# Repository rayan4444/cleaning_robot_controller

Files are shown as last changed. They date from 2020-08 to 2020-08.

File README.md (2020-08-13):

# Deck cleaning and staining robot

Hardware files for all the custom electronics in a deck cleaning and staining robot.
* Eagle files and documentation provided. See individual folder readme for details.
* Firmware for the STM32F407 was developed in C based on STM CubeMx libraries, but cannot be made public as of now.  

## Architecture

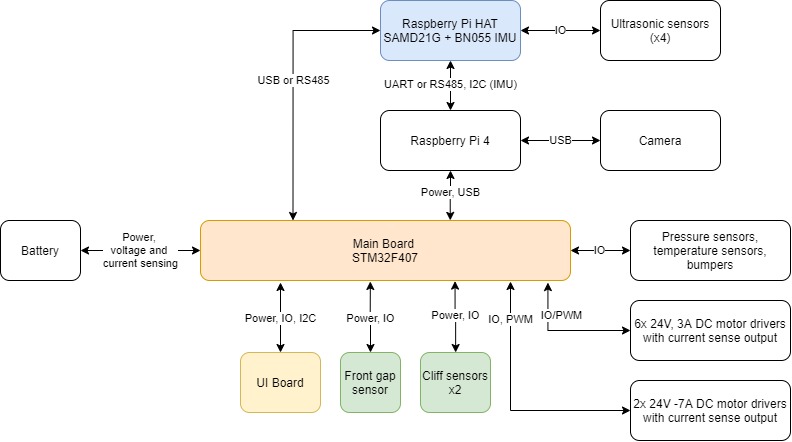
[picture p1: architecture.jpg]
Architecture


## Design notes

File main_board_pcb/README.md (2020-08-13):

# Robodeck Main Board

## Description
Main controller for motors, sensors and other peripherals. Features:
- 1x STM32F407 100pin microcontroller
- 6x 24V-3A motor drivers with fault detection, current sensing and current limiting
    - 2 with encoder lines
    - 4 simple
- 2x 24V- 10A motor drivers with fault detection, current sensing and current limiting
- 2x N-MOSFET Switches (up to 2A)
- 1x Hall effect current sensor on main input
- 1x Input voltage measurement
- 1x UART breakout
- 1x SPI breakout
- 1x I2C breakout
- 3x pressure sensor connectors
- 1x on board temperature and humidity sensor
- 2x connectors for external temperature sensors
- 2x Cliff sensor connectors
- 1x front gap sensor connector
- 2x 5V servo connectors
- 1x SMBUS BMS connector
- 1x RS-485 transceiver
- 2x bumpers connectors
- 1x SWD programming and debug header
- 1x UI board connector
- 2x USB outputs with power and data (up to 2.5A, data can be disconnected from one of the ports)
- 2x optional breakouts for Brushless ESC (share signal with high power motor drivers)
- 1x spare port breakout

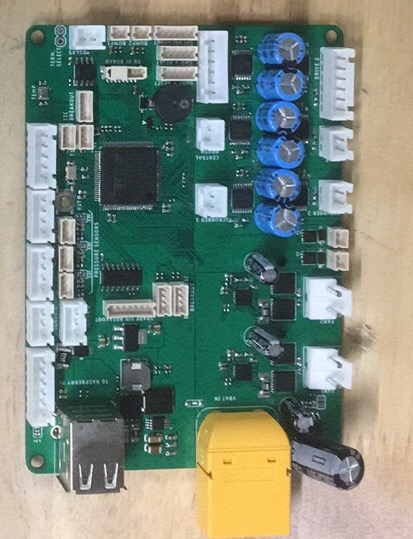
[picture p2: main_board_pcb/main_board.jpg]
main board

## Hardware connections
Microcontroller

|STM32 Pin | Peripheral| Signal|Notes|Test results|
|:---:|:---:|:---:|:---:|:---:|
|PC9 |**TIM3_CH4**|DRIVE1_A |PWM||
|PC12| GPIO OUT |DRIVE1_B||
|PD13| EXTI_13|DRIVE1_FAULT||  
|PB0| ADC1_CH8||DRIVE1_CURRENT||
|PB2| GPIO OUT| MOTOR_SLEEP |also BOOT1 pin|
|PC8|**TIM3_CH3**|DRIVE2_A |PWM|
|PC11|GPIO OUT|DRIVE2_B||
|PD12|EXTI_12|DRIVE2_FAULT||
|PB1| ADC_CH9|DRIVE2_CURRENT||
|PC6|**TIM3_CH1**|PRESSURE_PUMP_A|PWM|
|PA8|GPIO OUT|PRESSURE_PUMP_B||
|PD10|EXTI_10|PRESSURE_PUMP_FAULT||
|PC7|**TIM3_CH2**|CENTRAL_BRUSH_A|PWM|
|PC10|GPIO OUT|CENTRAL_BRUSH_B||
|PD11|EXTI_11|CENTRAL_BRUSH_FAULT||
|PC5|ADC1_CH5|CENTRAL_BRUSH_CURRENT||
|PE14|**TIM1_CH4**|SCRUBBER1_A|PWM|
|PE15|GPIO OUT|SCRUBBER1_B||
|PB15|EXTI_15|SCRUBBER1_FAULT||
|PA3|ADC1_CH3|SCRUBBER1_CURRENT|PWM|
|PE13|**TIM1_CH3**|SCRUBBER2_A|PWM|
|PE12|GPIO OUT|SCRUBBER2_B|| 
|PB14|EXTI_14|SCRUBBER2_FAULT||
|PC4|ADC1_CH14|SCRUBBER2_CURRENT||
|PD1|EXTI_1|BUMPER1||
|PD0|EXTI_0|BUMPER2||
|PD8|EXTI_8|ENCODER1||
|PD9|EXTI_9|ENCODER2|| 
|PD15|**TIM4_CH4**|SERVO1|PWM|
|PD14|**TIM4_CH3**|SERVO2|PWM|
|PB8|GPIO OUT|SOLENOID1||
|PB9|GPIO OUT|SOLENOID2||
|PE9|**TIM1_CH1**|STAINING_FAN1_A||
|PE8|GPIO OUT|STAINING_FAN1_B||
|PE6|EXTI_6|STAINING_FAN1_FAULT||
|PE11|**TIM1_CH2**|STAINING_FAN2_A||
|PE10|GPIO OUT|STAINING_FAN2_B||
|PE7|EXTI_7|STAINING_FAN2_FAULT||
|PB6|I2C1_SCL|SCL||
|PB7|i2C1_SDA|SDA||
|PD6|USART2_RX|RS485_RX||
|PD5|USART2_TX|RS485_TX||
|PE0|GPIO OUT|RS485_DIR||
|PB4|SPI1_MISO|MISO||
|PB5|SPI1_MOSI|MOSI||
|PD7|GPIO OUT|CS||
|PB3|SPI1_SCK|SCK||
|PA12|USB_DP|D_P||
|PA11|USB_DN|D_N||
|PA13|SWDIO|SWDIO||
|PA14|SWCLK|SWCLK||
|PA9|USART1_TX|USART1_TX|| 
|PA10|USART1_RX|USART1_RX||
|PB11|I2C2_SDA|SMBUS_SDA||
|PB10|I2C2_SCL|SMBUS_SCL|| 
|PB12|I2C2_SMBA|SMBUS_ALERT||
|PAB13|GPIO OUT|SMBUS_IO||
|PC2|ADC1_CH12|CLIFF1_OUT||
|PC3|ADC1_CH13|CLIFF2_OUT||
|PC0|ADC1_CH10|GAP_SENSE_1||
|PC1|ADC1_CH11|GAP_SENSE_2||
|PD4|EXTI_4|ONxOFF|from UI Board|
|PD3|EXTI_3|STARTxSTOP|from UI Board|
|PD2|EXTI_2|CLEANxSTAIN|from UI Board|
|PA4|DAC_1|GAP_CTL|to front gap sensor|
|PA5|DAC_2|CLIFF_CTL|to both cliff sensors|
|PC15|GPIO IN|EXT_TEMP2| DS18B20 temp sensor|  
|PC14|GPIO IN|EXT_TEMP1| DS18B20 temp sensor|  
|PA0|ADC1_CH0|PRESSURE1||
|PA6|ADC1_CH6|PRESSURE2||
|PA15|**TIM2_CH1**|BUZZER|st equivalent for tone library?|
|PA7|ADC1_CH7|PRESSURE3||GPIO OK|
|PE3|GPIO OUT|AMUX_S0|channel selection on analog mux|
|PE4|GPIO OUT|AMUX_S1|channel selection on analog mux|
|PE5|GPIO OUT|AMUX_S2|channel selection on analog mux|
|PA1|ADC1_CH1|AMUX_OUT|analog mux output|
|PA2|ADC1_CH2|LxCURRENT|current sensor output|
|PE1|GPIO OUT|SPARE_GPIO1||
|PE2|GPIO OUT|SPARE_GPIO2||

Signals from Analog Mux:

|Channel|S0/S1/S2|Signal|
|:---:|:---:|:---:|
|Y0|0/0/0|STAINING_FAN2_CURRENT|
|Y1|1/0/0|STAINING_FAN1_CURRENT|
|Y2|0/1/0|PRESSURE_PUMP_CURRENT|
|Y3|1/1/0|BAT_MEAS|
|Y4|1/0/0|-|
|Y5|1/0/1|SPARE_ANALOG1|
|Y6|1/1/0|-|
|Y7|1/1/1|SPARE_ANALOG2|

## Programming

- Using SWD: You can use a programmer (ex: Jlink or STlink) to program the baord via SWD. I included a cable with dupont wires to make it easier for you. If you have an ST development board (discovery or nucleo), you can usually re-use the STlink that is embedded on that baord to flash an external chip.

>if you are using Visual Studio Code, check out this [tutorial](https://github.com/rayan4444/vs_code_setup_tutorials/tree/master/STM32) to set up your development environment for STM32:
- Using UART: All STM32 chips come with a bootloader that lets you use UART to program them. If for some reason you don't want to use SWD to program the chip, you can still use UART. However this will require you to modify the PCB a little. In this version pin Boot 0 pulled low and pin PB2 pulled high. To use UART flashing Boot0 needs to be high and PB2 low. If needed, consult [this tutorial](http://stm32f4-discovery.net/2014/09/program-stm32f4-with-uart/)

## Errata
Manufacturing errors:
- test points names not marked on bottom silkscreen (layer missing from gerber?)
- inner layers shorted on milled slot for xt90 connector resulting in short between power and ground: to fix, saw off the milled slot on current boards. And in the future make sure to modify the library part

Errors noted when assembling:
- Pin 1 marking for analog mux is missing
- VBAT in polarity not marked on silkscreen
- XT90 connector polarity flipped (+ side on the circuit corresponds to the - side of the connector)
- Diode marking missing on FET switches
- +/-  markings missing on FET connectors
- wrong footprint for input 100uF through hole capacitor (too small)

Testing log:
- Board 0 (in shenzhen): many soldering issues. to be debugged gradually
- Board 1: 24V buck OK (5.35V, perfect), LDO OK (3.3V), Can prorgam through SWD. other peripherals not tested.
- Board 2: 24V buck OK (5.35V, perfect), LDO OK (3.3V), Can prorgam through SWD. other peripherals not tested.
- Board 3: 24V buck OK (5.38V, good), LDO OK (3.3V), Can program through SWD, other peripherals not tested.

> Some boards have burnt connectors. from debugging, sorry. one of them also has the main ninput capacitors missing, you can easily solder them up

>Note from Rayan: on all the boards I sent I did not solder the ferrite bead that connects GND and AGND because it made it easy to do basic tests. You can choose to use the ferrite bead from the BOM or short the connection with a 0 ohm resistor or some tin.

Other design errors:
- DRV8701 AVDD connected to 3.3v in V1. Make sure to disconnect AVDD from the 3.3v rail else the drivers overheat and don't work.
- Missing power on led indicator

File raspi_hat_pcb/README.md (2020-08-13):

# Raspberry Pi Hat

## Description
This board plugs onto a Raspberry pi and features:
- 1x ATSAMD21G18 MCU (Arduino Zero)
- 1x BNO055 IMU with jumpers to select the I2C host: Raspberry Pi or MCU
- 1x RS-485 transciever with jumper to select the UART host: Raspberry Pi or MCU
- 4x connectors for Ultrasonic sensors
- 1x FET driver for a small 5V fan to cool down the RPi

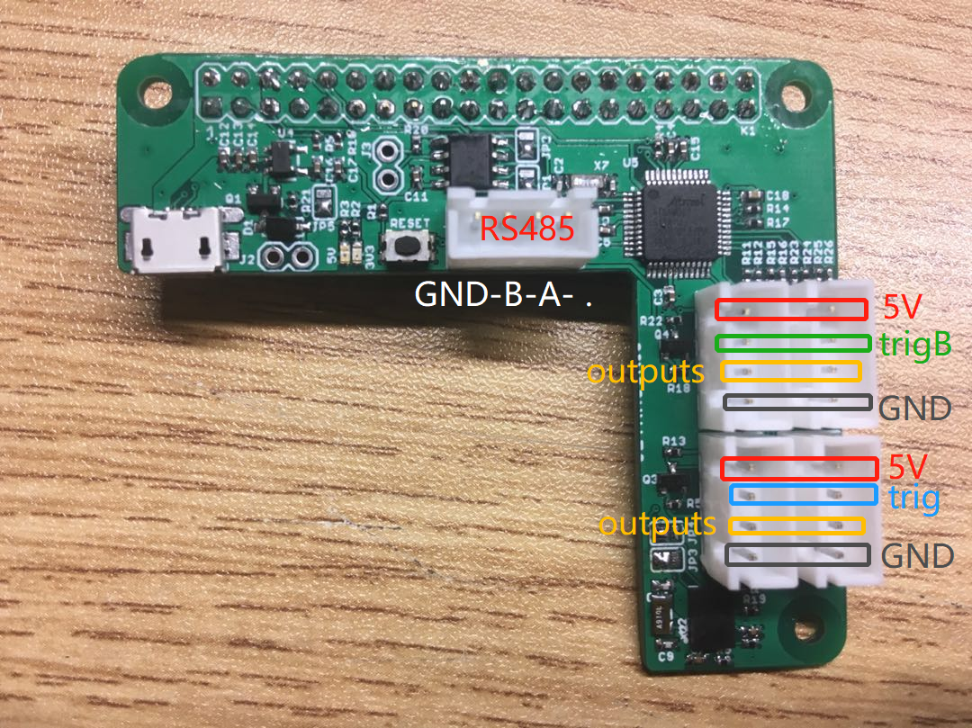
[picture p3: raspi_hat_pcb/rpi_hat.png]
Rpi hat

## Programming
The MCU on this board can normally be programmed directly via it's native USB port (using the microUSB connector on the board and in the Arduino IDE, choose Arduino Zero native USB as your Board. You might have to double-press the reset button before flashing). However the first time you use it, you need to burn the Arduino Zero bootloader on it first, using the SWD pins.

In this board, the SWD pins are connected to the Raspberry Pi connector so you can use the Raspberry pi to burn the bootloader, like explained in [this tutorial](https://learn.adafruit.com/programming-microcontrollers-using-openocd-on-raspberry-pi).

The soldered boards sent already have the Arduino bootloader burned and can be programmed directly.

## Hardware connections

MCU:

|ATSAMD21G18 Pin|Arduino Pin|Signal| Notes|
|:---:|:---:|:---:|:---:|
|PA5| A4 or 18|FAN_MCU| to toggle cooling fan from the MCU|
|PA10|1 or TX|MCU_TXD||
|PA11|0 or RX|MCU_RXD||
|PA12|22|RS485_DIR| controlling RS485 transceiver direction|
|PA15|5~|TRIG_B_| trigger pin for one pair of ultrasonic sensors|
|PA16| 11~|TRIG_|trigger pin for the other pair of ultrasonic sensors|
|PA17|13~|ECHO1| interrupt enabled|
|PA18|10~|ECHO2| interrupt enabled|
|PA19|12~|ECHO3|interrupt enabled|
|PA20|6~|ECHO4| interrupt enabled|
|PA21|7|IMU_INT| interrupt enabled|
|PA22|SDA|MCU_SDA| to IMU|
|PA23|SCL|MCU_SCL| to IMU|
|PA24|USB D-|USBD_N| to micro USB connector, for programming|
|PA25|USB D+|USBD_P| to micro USB connector, for programming|
|PA30|SWCLK|SWCLK|To Rpi,  for first time bootloader burning|
|PA31|SWDIO|SWDIO|To Rpi,  for first time bootlader burning|

Raspberry Pi:

|Raspberry Pi GPIO|Raspberry Pi Pin|Signal|Notes|
|:---:|:---:|:---:|:---:|
|GPIO 2|3|RPI_SDA|to IMU|
|GPIO 3|5|RPI_SCL|to IMU|
|GPIO 4|7|FAN_PI| to toggle cooling fan from the Rpi|
|GPIO 14|8|RPI_TX|RPI UART|
|GPIO 15|10|RPI_RX|RPI UART|
|GPIO 17|11|IMU_RST|to IMU|
|GPIO 18|12|RESET||
|GPIO 27|13|IMU_INT| to IMU|
|GPIO 24|18|MCU SWDIO|To burn bootloader to the MCU|
|GPIO 25|22|MCU SWCLK|To burn bootloader to the MCU|

Connectors:
- see pictures above

Jumper options:
- JP1 and JP2: select whether the MCU's UART talks to the Main board through RS485 or directly to the RPI
- JP3 and JP4: select whether the IMU connects to the MCU or the RPi

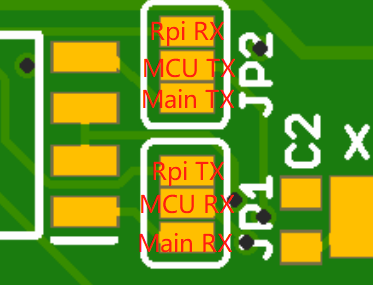
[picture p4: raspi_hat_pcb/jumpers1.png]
jumpers

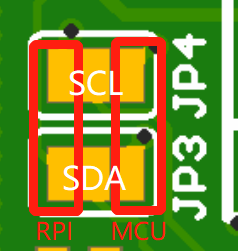
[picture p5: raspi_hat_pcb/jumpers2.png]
jumpers2


## Errata
Errors noticed when assemling:
- Pin 1 of IMU hard to spot
- Diode direction missing on D1
- R7 and C8 silkscreen unclear
- Ultrasonic sensors and RS485 connectors don't have a labelled pinout

Testing log:
- Tested all boards, bootloader burned.
- Communication with the IMU was tested with the Arduino MCU (I2C address 0x28): the jumpers were then set to commnuicate with the Raspberry Pi, but that communication hasn't been tested.
- Board 1: no problems
- Board 2: 5V red LED doesn't turn on but board works fine
- Board 3: no problems

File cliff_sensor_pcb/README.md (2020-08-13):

# Robodeck Cliff sensor 

## Description
This small board features a single TCRT5000 sensor and a votlage controlled current source to control the brightness of the IR LED in the sensor if needed/wanted. 
 
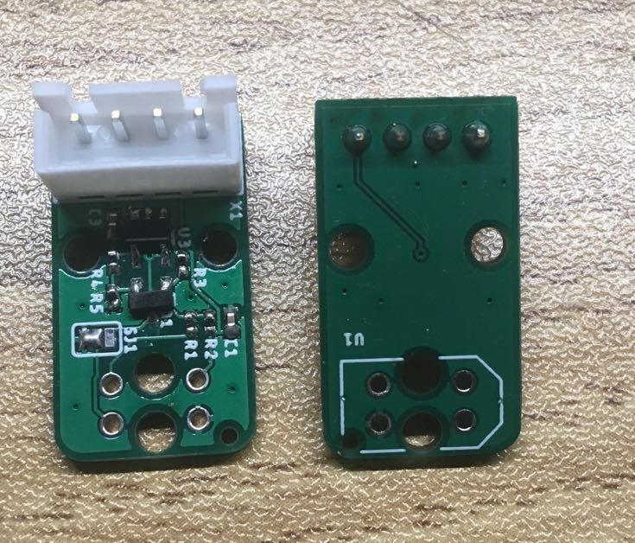
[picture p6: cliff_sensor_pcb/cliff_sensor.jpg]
cliff sensor


## Hardware connections 
JST XH Connector 4Pin, top view (left on the picture above), left to right:
- GND
- CLIFF_OUT: analog output of the cliff sensor
- CLIFF_CTRL: input to the voltage controlled current source
- 3V3

In constant current mode: 
- Solder a resistor on R1 to set the current 
- Solder JP1 to GND

In controlled current mode: 
- Connect CLIFF_CTRL signal to an analog voltage source (ex: STM32 DAC)
- Solder a 0 ohm resistor to R1
- Solder JP1 to CTRL

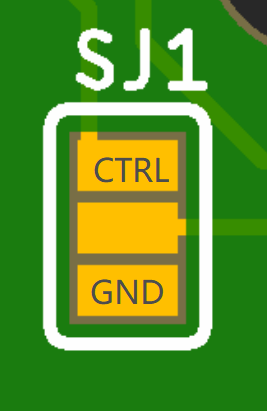
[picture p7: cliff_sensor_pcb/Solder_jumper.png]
solder jumper


## Errata
Errors noted when assembling: 
- forgot to label pin signals at the back 

Testing log:
- Not tested yet

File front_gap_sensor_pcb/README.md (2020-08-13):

# Robodeck Front gap sensor

## Description
This small board features two TCRT5000 sensors and a votlage controlled current source to control the brightness of the IR LEDs in the sensors if needed/wanted. 
 
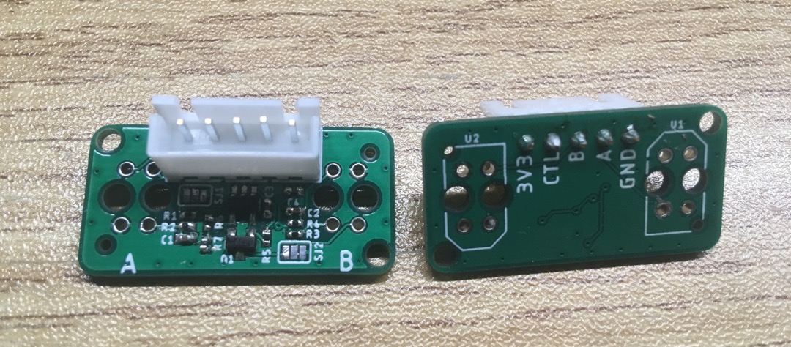
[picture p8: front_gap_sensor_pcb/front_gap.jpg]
front gap sensor


## Hardware connections 
Connections marked on the board.

In constant current mode: 
- Solder a resistor on R1 and R3 to set the current 
- Solder JP1 and JP2 to GND

In controlled current mode: 
- Connect CLIFF_CTRL signal to an analog voltage source (ex: STM32 DAC)
- Solder a 0 ohm resistor to R1 and R3
- Solder JP1 and JP2 to CTRL

>Note: the current source feeds both analog sensors together, not individually. 

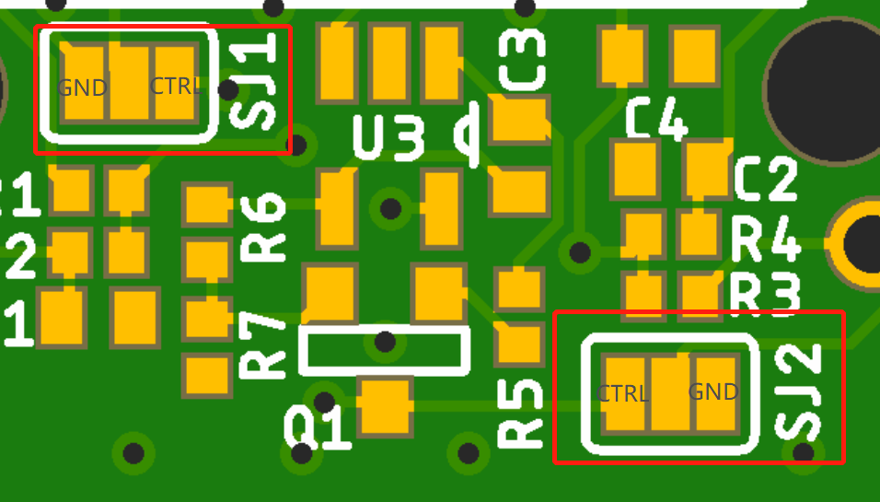
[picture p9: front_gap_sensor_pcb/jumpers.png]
solder jumper


## Errata
Errors noted when assembling: 
- nothing to note

Testing log:
- Not tested yet

## Open Issues

|Date|Issue|Responsible|Status|
|:---:|:---:|:---:|:---:|
|17.6.2020|In the current schematics, R1&R3 value should be 57.6Ω|||
|10.07.2020|Change componenets as per the below image|||
|20.07.2020|Seperate the TX+2xRX from the board via a dedicated connector|||
|20.07.2020|Future: merge the gap sensor electronics into the mainboard||||

new gap sensor 2Rx&1Tx

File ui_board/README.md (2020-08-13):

# UI board 

## Description
This board has the buttons and LED indicators for user interface:
* 3x momentary push buttons with some hardware debouncing
* 2x RGB LEDs, common anode.
* 1x Blue LED
* 1x Red LED tied to a green LED (tristate control)

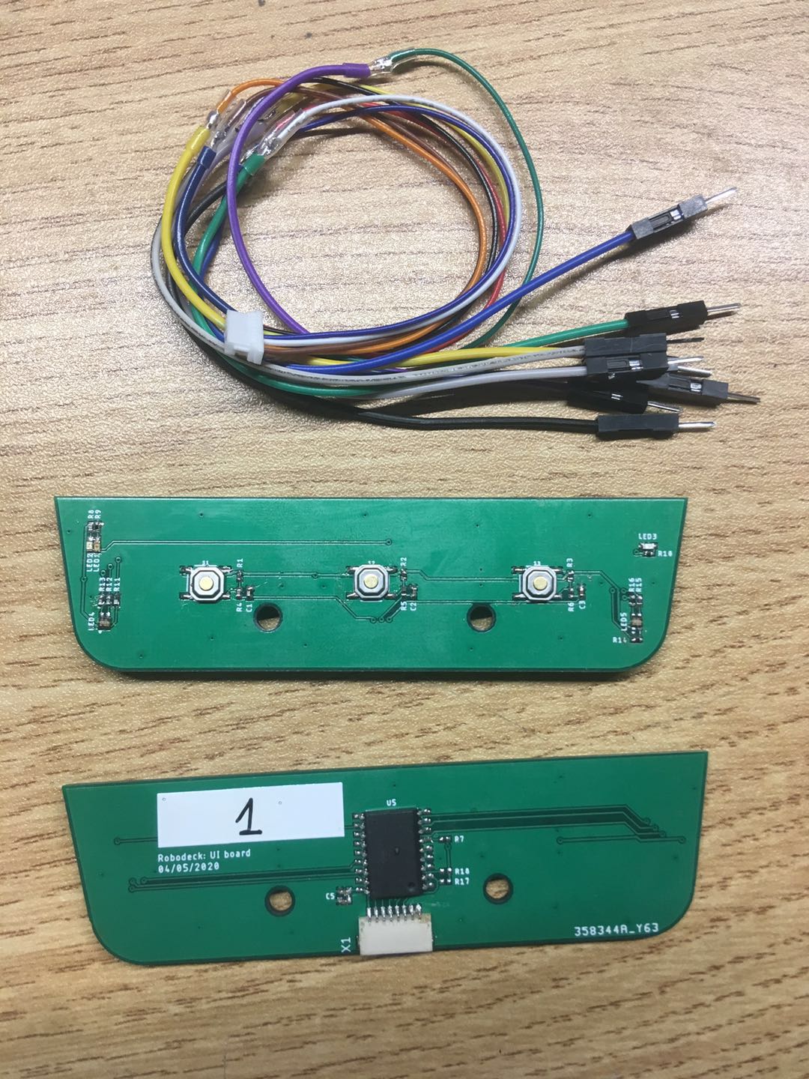
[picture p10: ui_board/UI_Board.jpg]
UI board


## Hardware connections
On JST SH (1mm spacing) 8pin connector side, left to right:
|Pin|Signal| Notes|
|:---:|:---:|:---:|
|1|3V3|Supply to the board|
|2|Clean/Stain Button|LOW when pressed |
|3|Start/Stop Button|LOW when pressed|
|4|On/Off Button|LOW when pressed|
|5|I2C SCL|3.3V level, footprints for pullup resistors are available but not populated by default|
|6|I2C SDA|3.3V level, footprints for pullup resistors are available but not populated by default|
|7|GND||
|8|GND||

## Test sketch
There is an Arduino sketch to test the basic features of the UI board. A test cable with male Dupont ends is provided to help connect the UI board to a breadboard, Arduino or other development boards.

## Errata
Errors noted when assembling:
- MCP220008 pin one marking missing
- C4 and C5 silkscreen unclear
- LED cathode markings covered or too small
- LED1 and LED2 a little too close.

Test report:
- Board 1: nothing wrong so far
- Board 2: nothing wrong so far
- Board 3: nothing wrong so far

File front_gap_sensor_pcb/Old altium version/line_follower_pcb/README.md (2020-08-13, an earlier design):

# Test notes
* Separator needed between the two IR sensors

# Errata

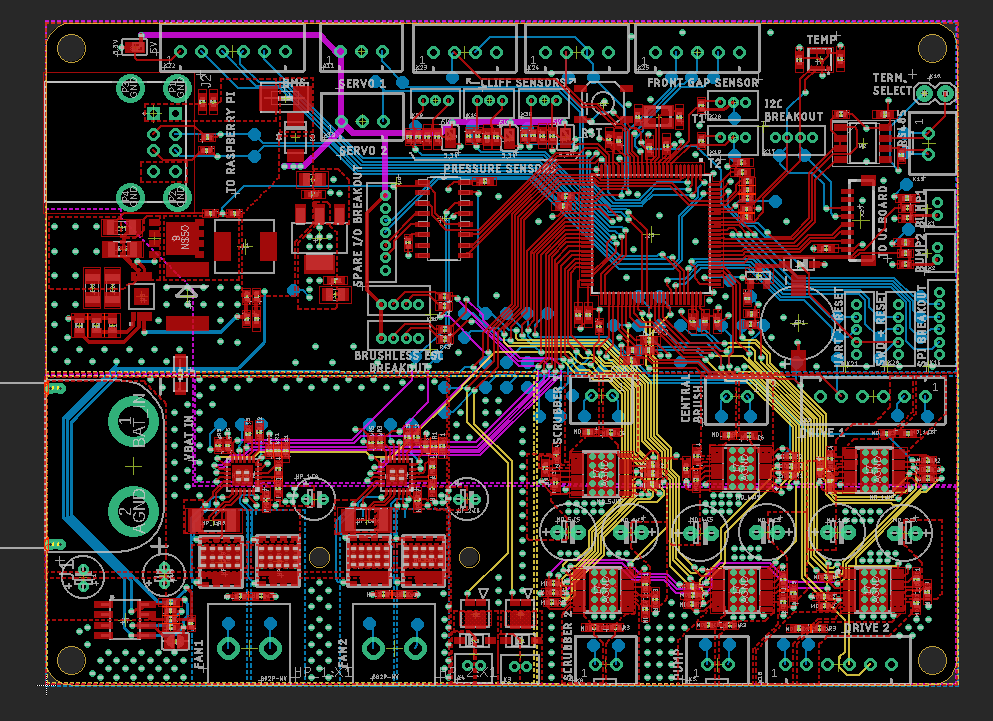
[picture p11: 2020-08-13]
main_board_pcb/layout.PNG

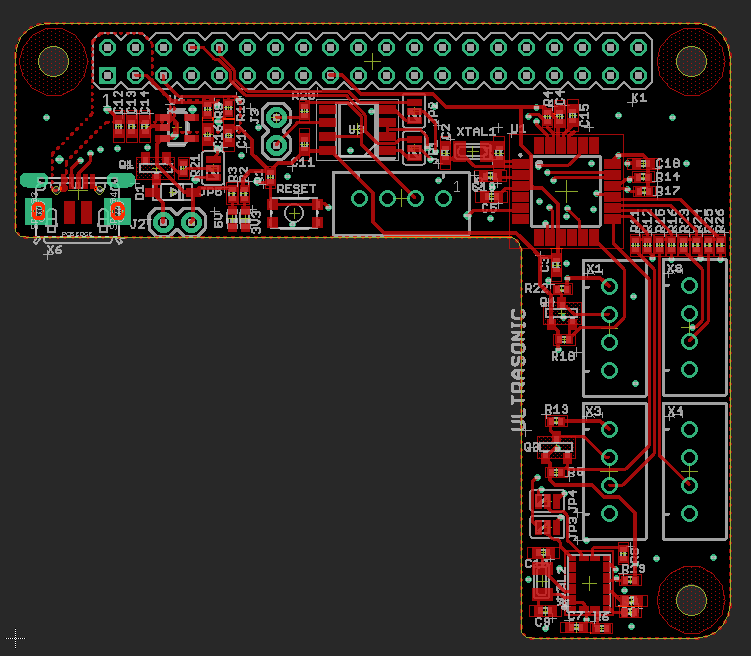
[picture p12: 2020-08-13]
raspi_hat_pcb/layout.PNG

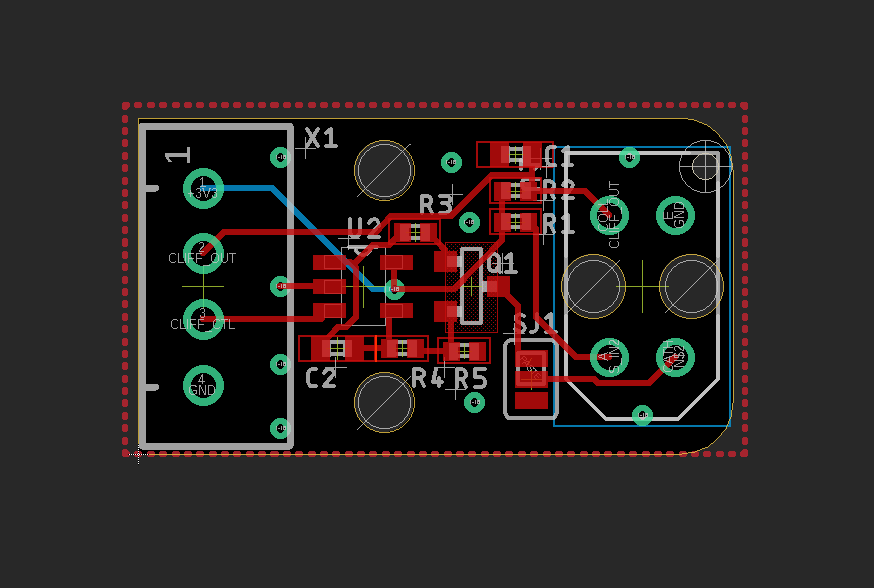
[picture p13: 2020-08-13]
cliff_sensor_pcb/layout.PNG

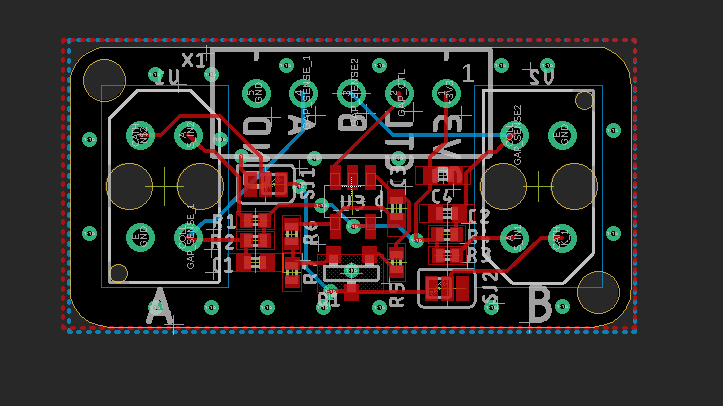
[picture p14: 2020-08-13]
front_gap_sensor_pcb/layout.PNG

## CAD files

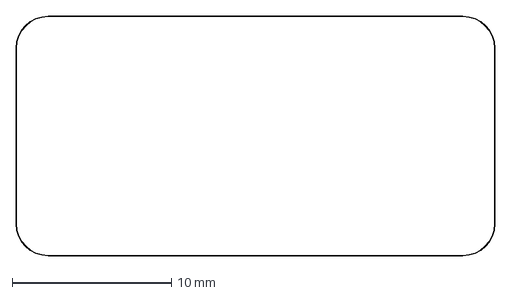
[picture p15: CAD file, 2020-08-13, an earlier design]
front_gap_sensor_pcb/Old altium version/line_follower_pcb/outline_lf.dxf
30.0 x 15.0 mm

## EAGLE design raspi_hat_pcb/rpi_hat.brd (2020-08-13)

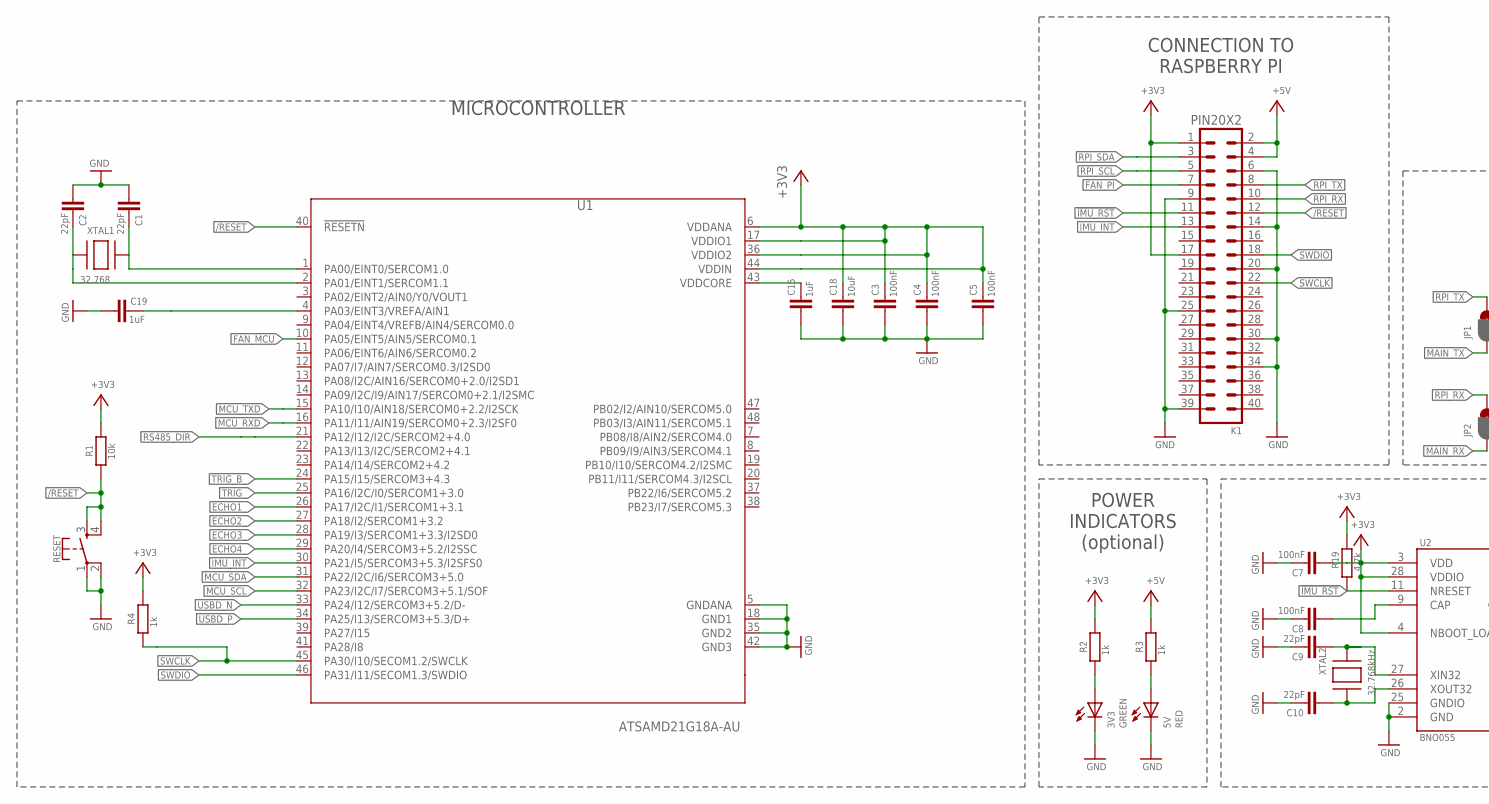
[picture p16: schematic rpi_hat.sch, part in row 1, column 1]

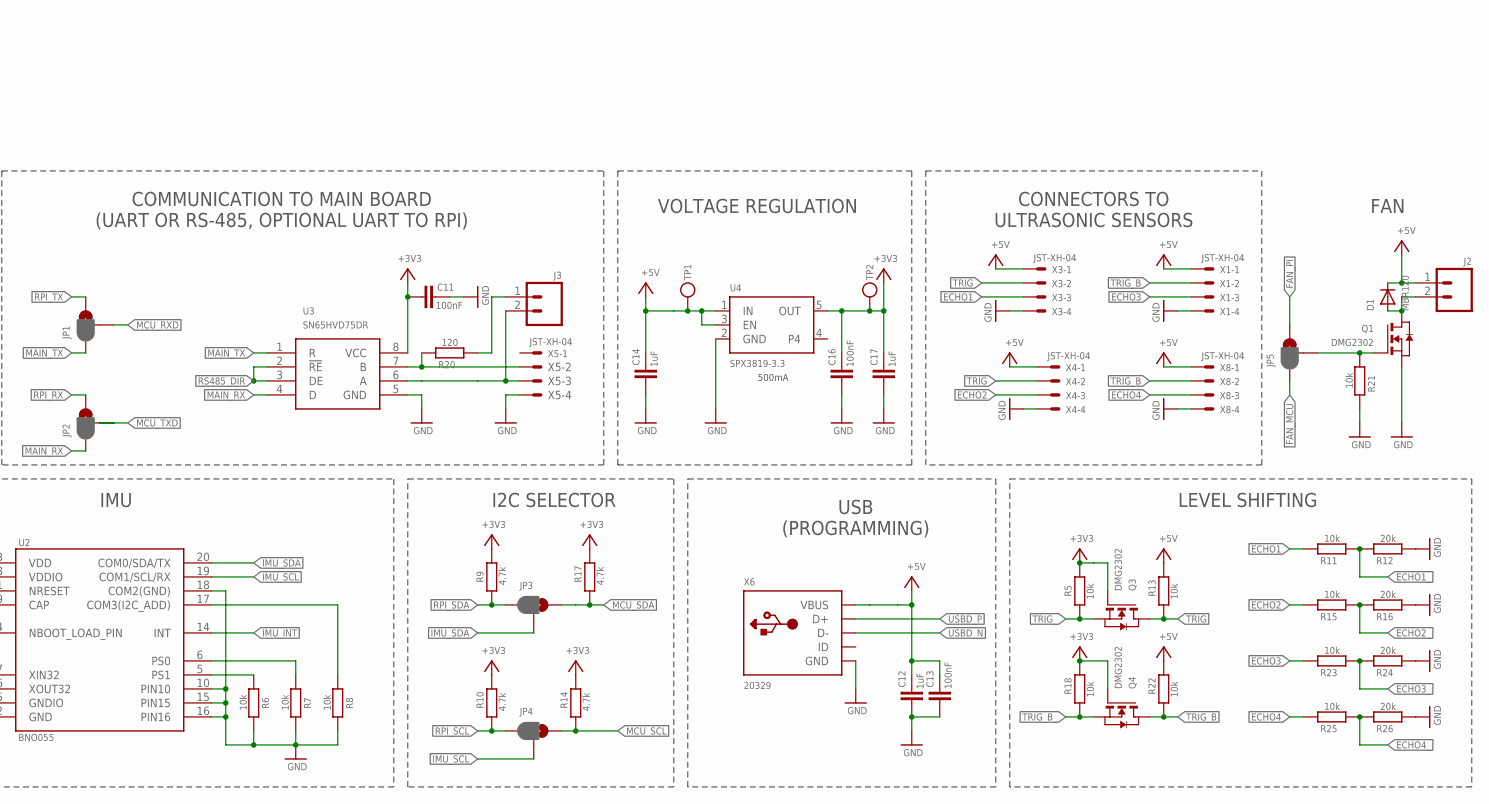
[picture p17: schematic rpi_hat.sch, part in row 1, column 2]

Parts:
3V3: GREEN; CHIP-LED0603
5V: RED; CHIP-LED0603
C1, C2, C9, C10: 22pF; C0402
C3, C4, C5, C7, C8, C11, C13, C16: 100nF; C0402
C12, C14, C15, C17, C19: 1uF; C0402
C18: 10uF; C0402
D1: MBR120; SOD-123
J2, J3: CONN_02; 1X02
JP1, JP2, JP3, JP4, JP5: SPARKFUN-PASSIVES_JUMPER_PAD-3-1&2_NC_BY_PASTE; SPARKFUN-PASSIVES_PAD-HUMPER-3-1&2_NC_BY_PASTE_YES_SILK_FUL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
K1: PIN20X2; PIN_20X2
Q1, Q3, Q4: DMG2302; SOT-23
R1, R5, R6, R7, R8, R11, R13, R15, R18, R21, R22, R23, R25: 10k; R0402
R2, R3, R4: 1k; R0402
R9, R10, R14, R17, R19: 4.7k; R0402
R12, R16, R24, R26: 20k; R0402
R20: 120; R0402
RESET: MOMENTARY-SWITCH-SPST-2-SMD-4.6X2.8MM; TACTILE_SWITCH_SMD_4.6X2.8MM
TP1, TP2: MICROBUILDER_TESTPOINTROUND1MM; MICROBUILDER_TESTPOINT_ROUND_1MM
U1: ATSAMD21G18A-AU; QFP50P900X900X120-48N
U2: BNO055; LGA28R50P4X10_380X520X100
U3: SN65HVD75DR; SOIC127P600X175-8N
U4: SPX3819-3.3; SOT23-5
X1, X3, X4, X5, X8: JST-XH-04; JST-XH-04-PACKAGE-ROUND-PAD
X6: 20329; 4UCONN_20329_V2
XTAL1: 32.768; XTAL3215
XTAL2: 32.768kHz; ADAFRUIT2_XTAL3215

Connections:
!IMU_RST: K1.11, R19.1, U2.11 (NRESET)
+3V3: C3.1, C4.1, C5.1, C7.2, C11.2, C16.1, C17.1, C18.1, K1.1, K1.17, Q3.G, Q4.G, R1.2, R2.2, R4.2, R5.2, R9.2, R10.2, R14.2, R17.2, R18.2, R19.2, TP2.P$1, U1.6 (VDDANA), U1.17 (VDDIO1), U1.36 (VDDIO2), U1.44 (VDDIN), U2.3 (VDD), U2.4 (NBOOT_LOAD_PIN), U2.28 (VDDIO), U3.8 (VCC), U4.5 (OUT)
+5V: C12.1, C13.1, C14.1, D1.C, J2.1, K1.2, K1.4, R3.2, R13.2, R22.2, TP1.P$1, U4.1 (IN), U4.3 (EN), X1.1, X3.1, X4.1, X6.VBUS, X8.1
/RESET: K1.12, R1.1, RESET.3, RESET.4, U1.40 (!RESETN)
ECHO1: R11.2, X3.3
ECHO1_: R11.1, R12.2, U1.26 (PA17/I2C/I1/SERCOM1+3.1)
ECHO2: R15.2, X4.3
ECHO2_: R15.1, R16.2, U1.27 (PA18/I2/SERCOM1+3.2)
ECHO3: R23.2, X1.3
ECHO3_: R23.1, R24.2, U1.28 (PA19/I3/SERCOM1+3.3/I2SD0)
ECHO4: R25.2, X8.3
ECHO4_: R25.1, R26.2, U1.29 (PA20/I4/SERCOM3+5.2/I2SSC)
FAN_MCU: JP5.1, U1.10 (PA05/EINT5/AIN5/SERCOM0.1)
FAN_PI: JP5.3, K1.7
GND: 3V3.C, 5V.C, C1.2, C2.2, C3.2, C4.2, C5.2, C7.1, C8.1, C9.1, C10.1, C11.1, C12.2, C13.2, C14.2, C15.2, C16.2, C17.2, C18.2, C19.2, K1.6, K1.9, K1.14, K1.20, K1.25, K1.30, K1.34, K1.39, Q1.S, R6.2, R7.2, R8.2, R12.1, R16.1, R21.2, R24.1, R26.1, RESET.1, RESET.2, U1.5 (GNDANA), U1.18 (GND1), U1.35 (GND2), U1.42 (GND3), U2.2 (GND), U2.10 (PIN10), U2.15 (PIN15), U2.16 (PIN16), U2.18 (COM2(GND)), U2.25 (GNDIO), U3.5 (GND), U4.2 (GND), X1.4, X3.4, X4.4, X5.4, X6.BASE@1 (GND), X6.BASE@2 (GND), X6.GND, X6.SPRT@1 (GND), X6.SPRT@2 (GND), X6.SPRT@3 (GND), X6.SPRT@4 (GND), X8.4
IMU_INT: K1.13, U1.30 (PA21/I5/SERCOM3+5.3/I2SFS0), U2.14 (INT)
IMU_SCL: JP4.2, U2.19 (COM1/SCL/RX)
IMU_SDA: JP3.2, U2.20 (COM0/SDA/TX)
MAIN_RX: JP2.1, U3.4 (D)
MAIN_TX: JP1.1, U3.1 (R)
MCU_RXD: JP1.2, U1.16 (PA11/I11/AIN19/SERCOM0+2.3/I2SF0)
MCU_SCL: JP4.3, R14.1, U1.32 (PA23/I2C/I7/SERCOM3+5.1/SOF)
MCU_SDA: JP3.3, R17.1, U1.31 (PA22/I2C/I6/SERCOM3+5.0)
MCU_TXD: JP2.2, U1.15 (PA10/I10/AIN18/SERCOM0+2.2/I2SCK)
unnamed: J3.1, R20.1
unnamed: C2.1, U1.2 (PA01/EINT1/SERCOM1.1), XTAL1.P$1
unnamed: C1.1, U1.1 (PA00/EINT0/SERCOM1.0), XTAL1.P$2
unnamed: C15.1, U1.43 (VDDCORE)
unnamed: JP5.2, Q1.G, R21.1
unnamed: D1.A, J2.2, Q1.D
unnamed: R6.1, U2.5 (PS1)
unnamed: R7.1, U2.6 (PS0)
unnamed: C19.1, U1.4 (PA03/EINT3/VREFA/AIN1)
unnamed: C8.2, U2.9 (CAP)
unnamed: C10.2, U2.26 (XOUT32), XTAL2.P$1
unnamed: C9.2, U2.27 (XIN32), XTAL2.P$2
unnamed: 3V3.A, R2.1
unnamed: R8.1, U2.17 (COM3(I2C_ADD))
unnamed: 5V.A, R3.1
unnamed: R20.2, U3.7 (B), X5.2
unnamed: J3.2, U3.6 (A), X5.3
RPI_RX: JP2.3, K1.10
RPI_SCL: JP4.1, K1.5, R10.1
RPI_SDA: JP3.1, K1.3, R9.1
RPI_TX: JP1.3, K1.8
RS485_DIR: U1.21 (PA12/I12/I2C/SERCOM2+4.0), U3.2 (!RE), U3.3 (DE)
SWCLK: K1.22, R4.1, U1.45 (PA30/I10/SECOM1.2/SWCLK)
SWDIO: K1.18, U1.46 (PA31/I11/SECOM1.3/SWDIO)
TRIG: Q3.D, R13.1, X3.2, X4.2
TRIG_: Q3.S, R5.1, U1.25 (PA16/I2C/I0/SERCOM1+3.0)
TRIG_B: Q4.D, R22.1, X1.2, X8.2
TRIG_B_: Q4.S, R18.1, U1.24 (PA15/I15/SERCOM3+4.3)
USBD_N: U1.33 (PA24/I12/SERCOM3+5.2/D-), X6.D-
USBD_P: U1.34 (PA25/I13/SERCOM3+5.3/D+), X6.D+

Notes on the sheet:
CONNECTION TO RASPBERRY PI
IMU
CONNECTORS TO ULTRASONIC SENSORS
I2C SELECTOR
POWER INDICATORS (optional)
COMMUNICATION TO MAIN BOARD (UART OR RS-485, OPTIONAL UART TO RPI)
USB (PROGRAMMING)
VOLTAGE REGULATION
500mA
MICROCONTROLLER
LEVEL SHIFTING
FAN

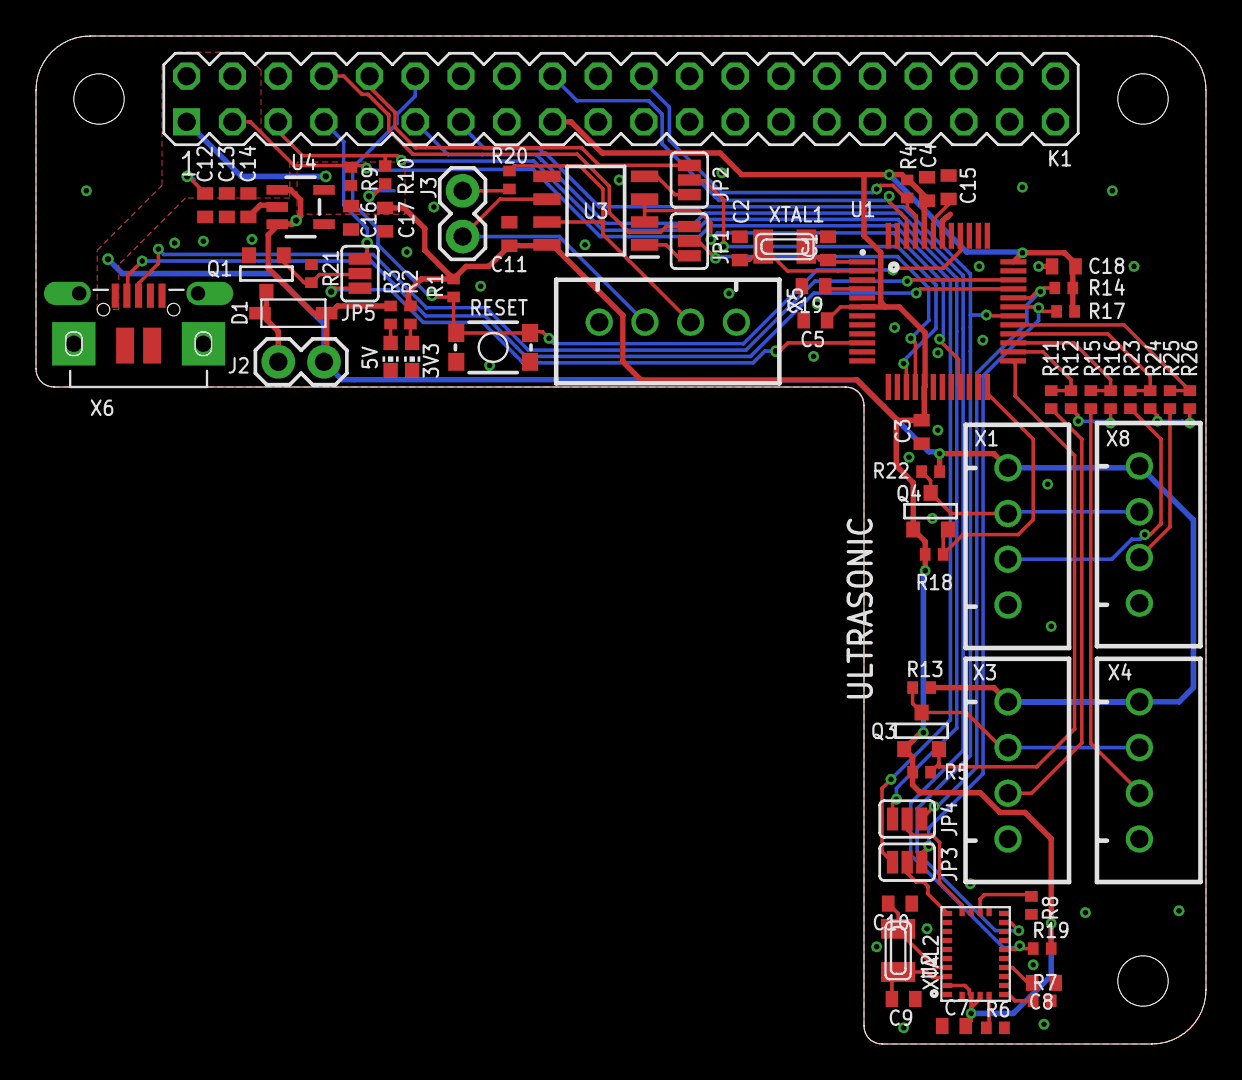
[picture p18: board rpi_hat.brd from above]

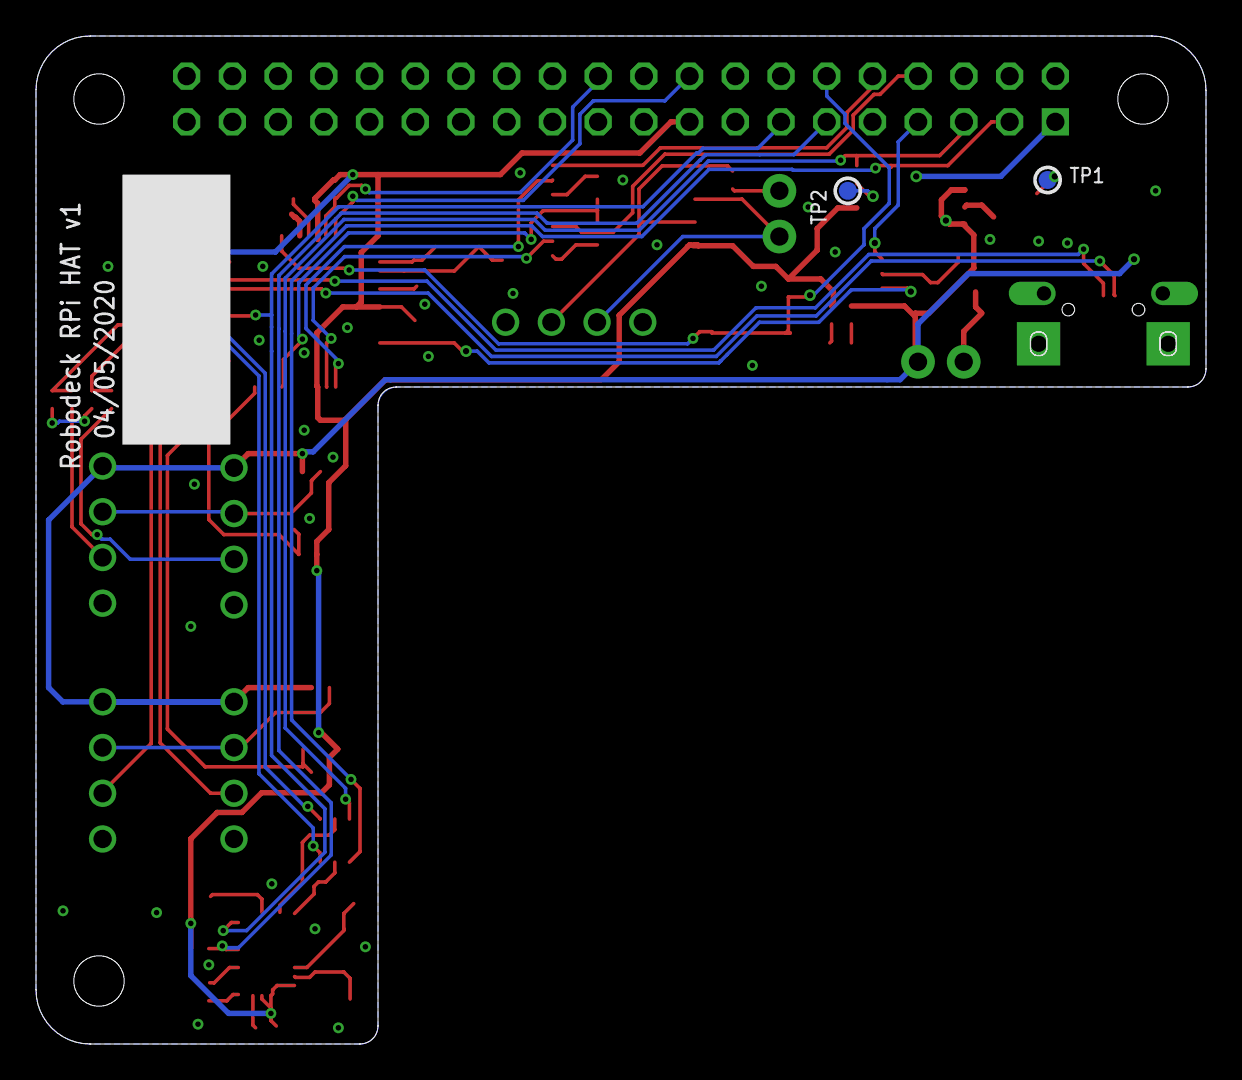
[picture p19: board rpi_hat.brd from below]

Board: 2 copper layers, 65.0 x 56.0 mm, 73 parts (2 on the bottom side), 54 nets.

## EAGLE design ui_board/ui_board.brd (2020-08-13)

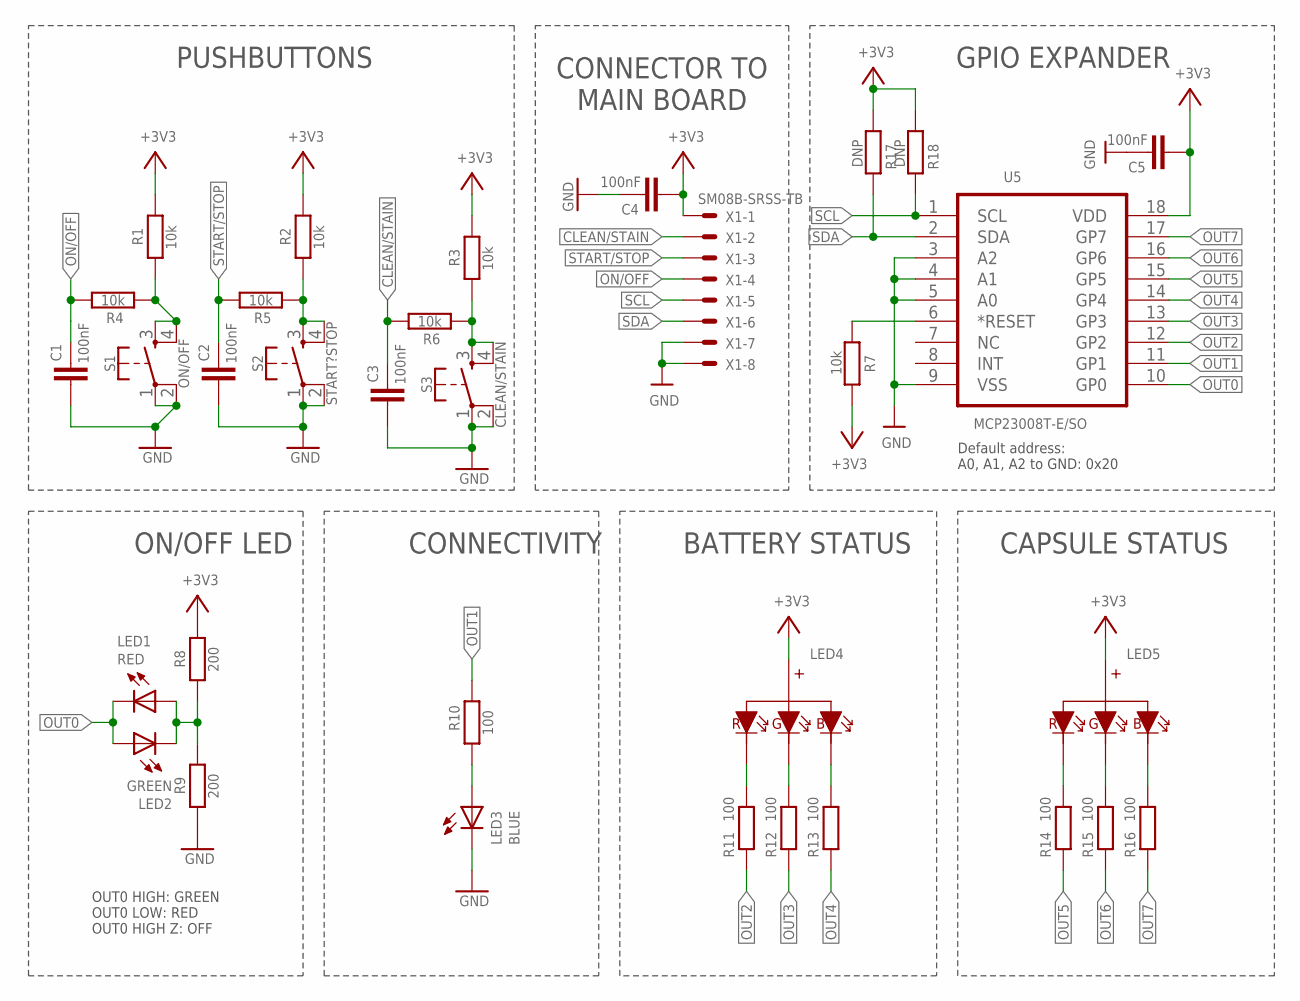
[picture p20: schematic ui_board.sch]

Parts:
C1, C2, C3, C4, C5: 100nF; C0402
LED1: RED; CHIP-LED0603
LED2: GREEN; CHIP-LED0603
LED3: BLUE; CHIP-LED0603
LED4, LED5: RGB_CAV1; 19-037A/RSGHBHW
R1, R2, R3, R4, R5, R6, R7: 10k; R0402
R8, R9: 200; R0402
R10, R11, R12, R13, R14, R15, R16: 100; R0402
R17, R18: DNP; R0402
S1: ON/OFF; TACTILE_SWITCH_SMD_5.2MM
S2: START?STOP; TACTILE_SWITCH_SMD_5.2MM
S3: CLEAN/STAIN; TACTILE_SWITCH_SMD_5.2MM
U5: MCP23008T-E/SO; SOIC127P1030X265-18N
X1: SM08B-SRSS-TB

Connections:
+3V3: C4.2, C5.2, LED4.A, LED5.A, R1.2, R2.2, R3.2, R7.2, R8.2, R17.1, R18.1, U5.18 (VDD), X1.1
CLEAN/STAIN: C3.1, R6.2, X1.2
GND: C1.2, C2.2, C3.2, C4.1, C5.1, LED3.C, R9.1, S1.1, S1.2, S2.1, S2.2, S3.1, S3.2, U5.3 (A2), U5.4 (A1), U5.5 (A0), U5.9 (VSS), X1.7, X1.8
unnamed: LED3.A, R10.1
unnamed: LED4.R, R11.2
unnamed: R1.1, R4.1, S1.3, S1.4
unnamed: R2.1, R5.1, S2.3, S2.4
unnamed: R3.1, R6.1, S3.3, S3.4
unnamed: LED4.G, R12.2
unnamed: LED4.B, R13.2
unnamed: LED5.R, R14.2
unnamed: LED5.G, R15.2
unnamed: LED5.B, R16.2
unnamed: LED1.A, LED2.C, R8.1, R9.2
unnamed: R7.1, U5.6 (*RESET)
ON/OFF: C1.1, R4.2, X1.4
OUT0: LED1.C, LED2.A, U5.10 (GP0)
OUT1: R10.2, U5.11 (GP1)
OUT2: R11.1, U5.12 (GP2)
OUT3: R12.1, U5.13 (GP3)
OUT4: R13.1, U5.14 (GP4)
OUT5: R14.1, U5.15 (GP5)
OUT6: R15.1, U5.16 (GP6)
OUT7: R16.1, U5.17 (GP7)
SCL: R18.2, U5.1 (SCL), X1.5
SDA: R17.2, U5.2 (SDA), X1.6
START/STOP: C2.1, R5.2, X1.3

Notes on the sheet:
ON/OFF LED
CONNECTIVITY
BATTERY STATUS
CAPSULE STATUS
PUSHBUTTONS
CONNECTOR TO MAIN BOARD
Default address: A0, A1, A2 to GND: 0x20
OUT0 HIGH: GREEN OUT0 LOW: RED OUT0 HIGH Z: OFF
GPIO EXPANDER

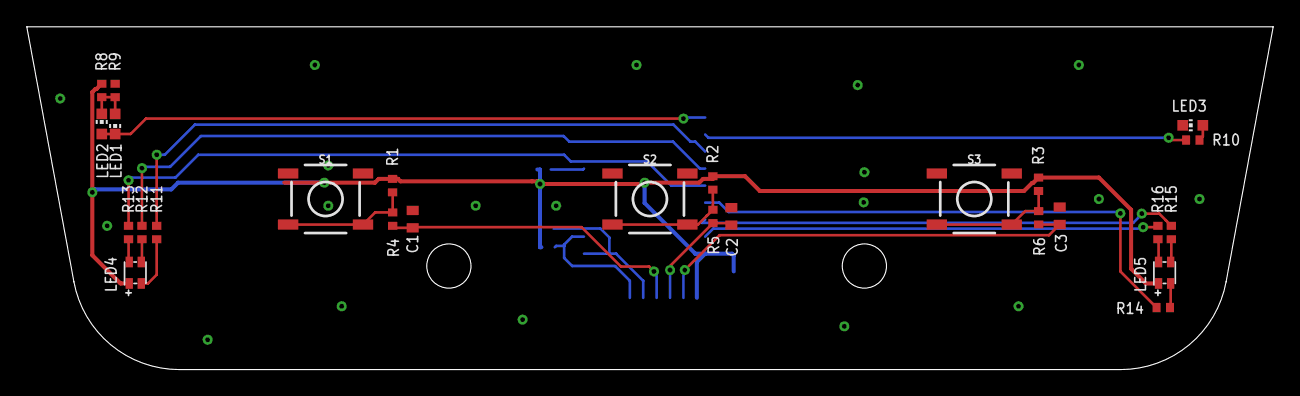
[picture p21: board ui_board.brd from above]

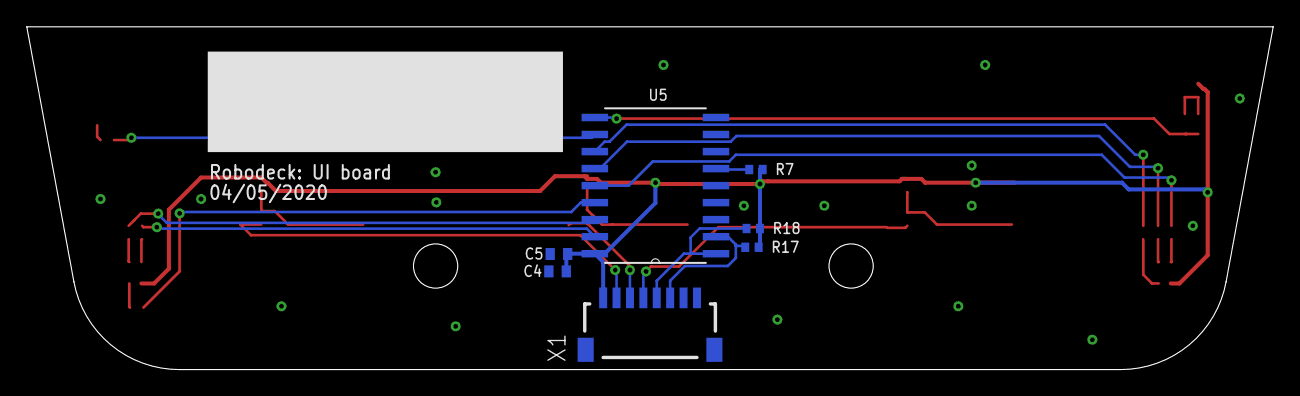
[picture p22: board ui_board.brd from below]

Board: 2 copper layers, 93.0 x 25.6 mm, 33 parts (7 on the bottom side), 27 nets.

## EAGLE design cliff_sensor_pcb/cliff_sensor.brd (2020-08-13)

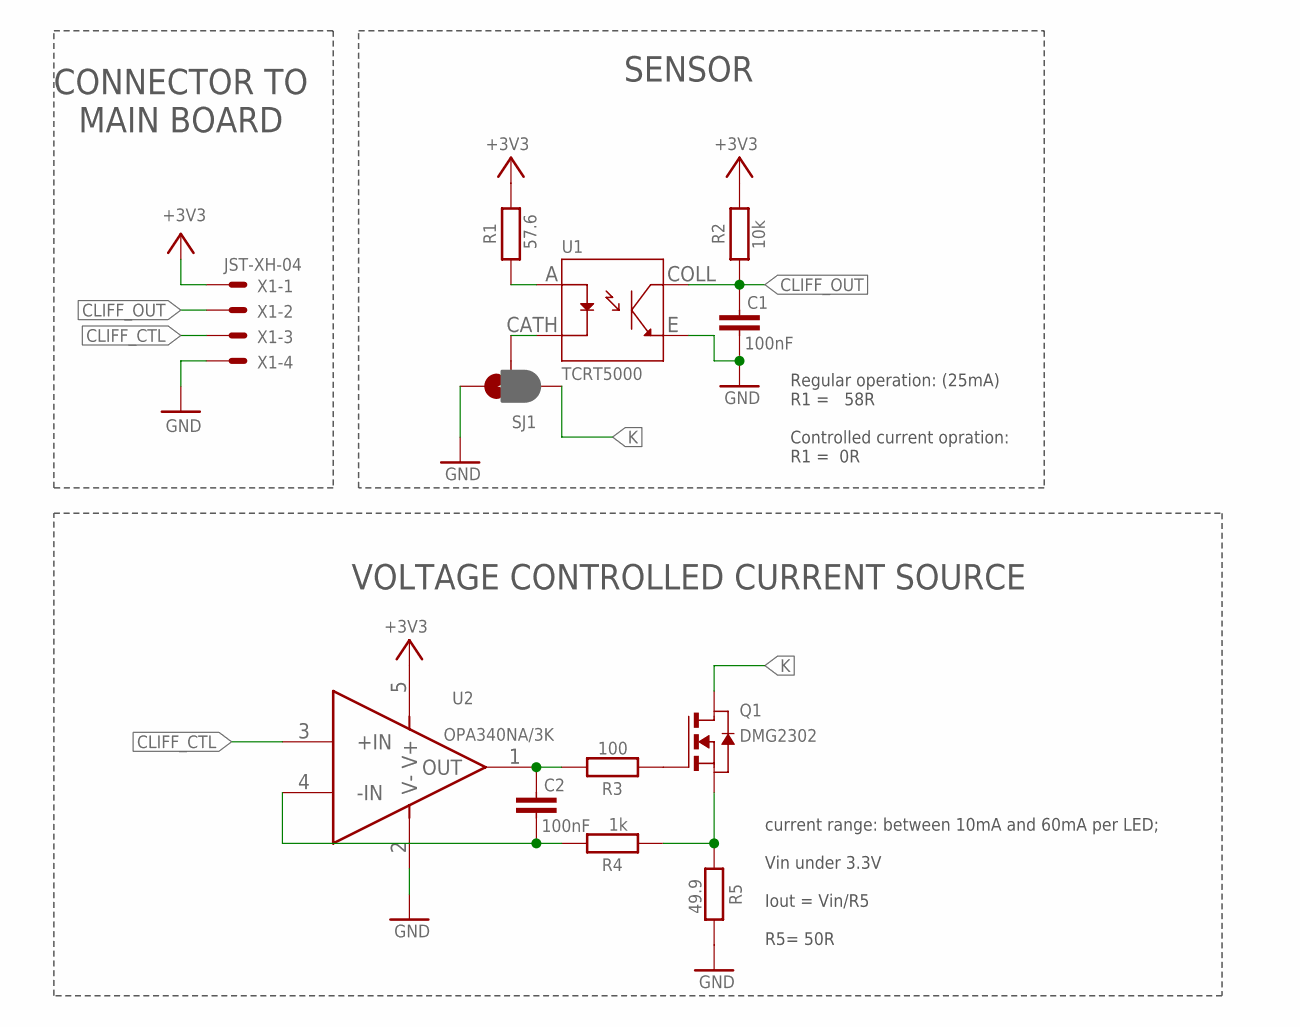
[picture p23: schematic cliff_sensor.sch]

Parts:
C1, C2: 100nF; C0402
Q1: DMG2302; SOT-23
R1: 57.6; R0402
R2: 10k; R0402
R3: 100; R0402
R4: 1k; R0402
R5: 49.9; R0402
SJ1: SPARKFUN-PASSIVES_JUMPER_PAD-3-1&2_NC_BY_PASTE; SPARKFUN-PASSIVES_PAD-HUMPER-3-1&2_NC_BY_PASTE_YES_SILK_FUL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
U1: TCRT5000; OPTO_TCRT5000
U2: OPA340NA/3K; SOT95P280X145-5N
X1: JST-XH-04; JST-XH-04-PACKAGE-ROUND-PAD

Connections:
+3V3: R1.2, R2.2, U2.5 (V+), X1.1
CLIFF_CTL: U2.3 (+IN), X1.3
CLIFF_OUT: C1.2, R2.1, U1.COLL, X1.2
GND: C1.1, R5.2, SJ1.3, U1.E, U2.2 (V-), X1.4
K: Q1.D, SJ1.1
unnamed: SJ1.2, U1.CATH
unnamed: C2.2, R3.2, U2.1 (OUT)
unnamed: C2.1, R4.2, U2.4 (-IN)
unnamed: Q1.G, R3.1
unnamed: Q1.S, R4.1, R5.1
S_IN2: R1.1, U1.A

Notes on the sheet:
Regular operation: (25mA) R1 = 58R Controlled current opration: R1 = 0R
SENSOR
VOLTAGE CONTROLLED CURRENT SOURCE
current range: between 10mA and 60mA per LED; Vin under 3.3V Iout = Vin/R5 R5= 50R
CONNECTOR TO MAIN BOARD

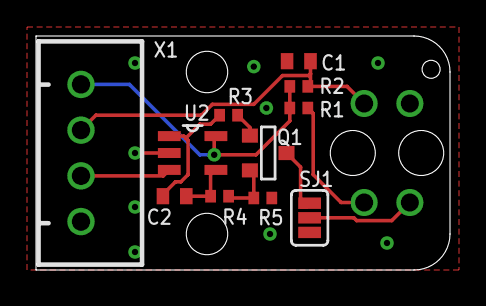
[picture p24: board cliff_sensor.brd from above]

Board: 2 copper layers, 23.0 x 13.0 mm, 12 parts (1 on the bottom side), 11 nets.

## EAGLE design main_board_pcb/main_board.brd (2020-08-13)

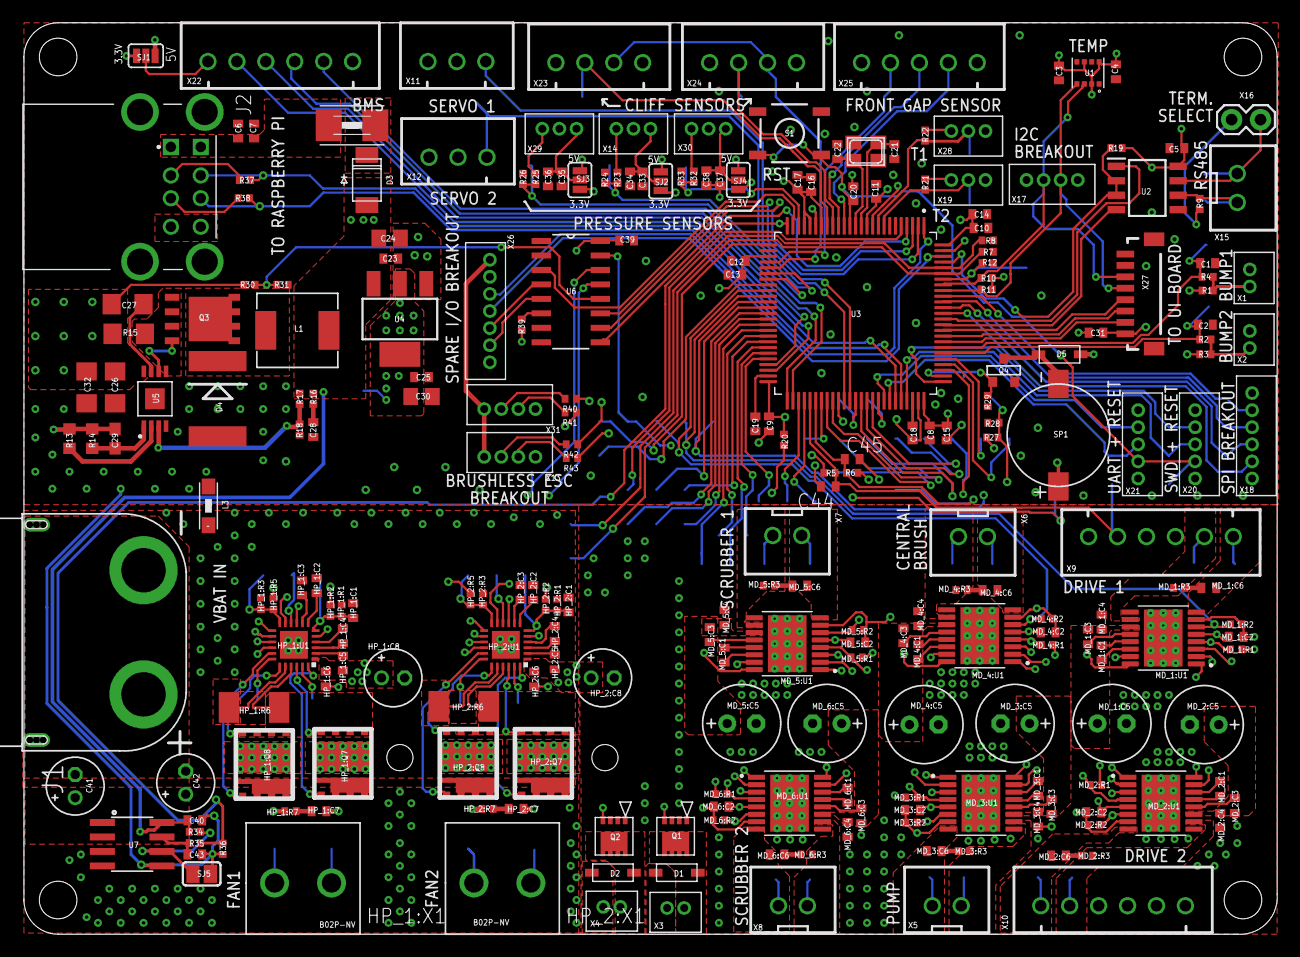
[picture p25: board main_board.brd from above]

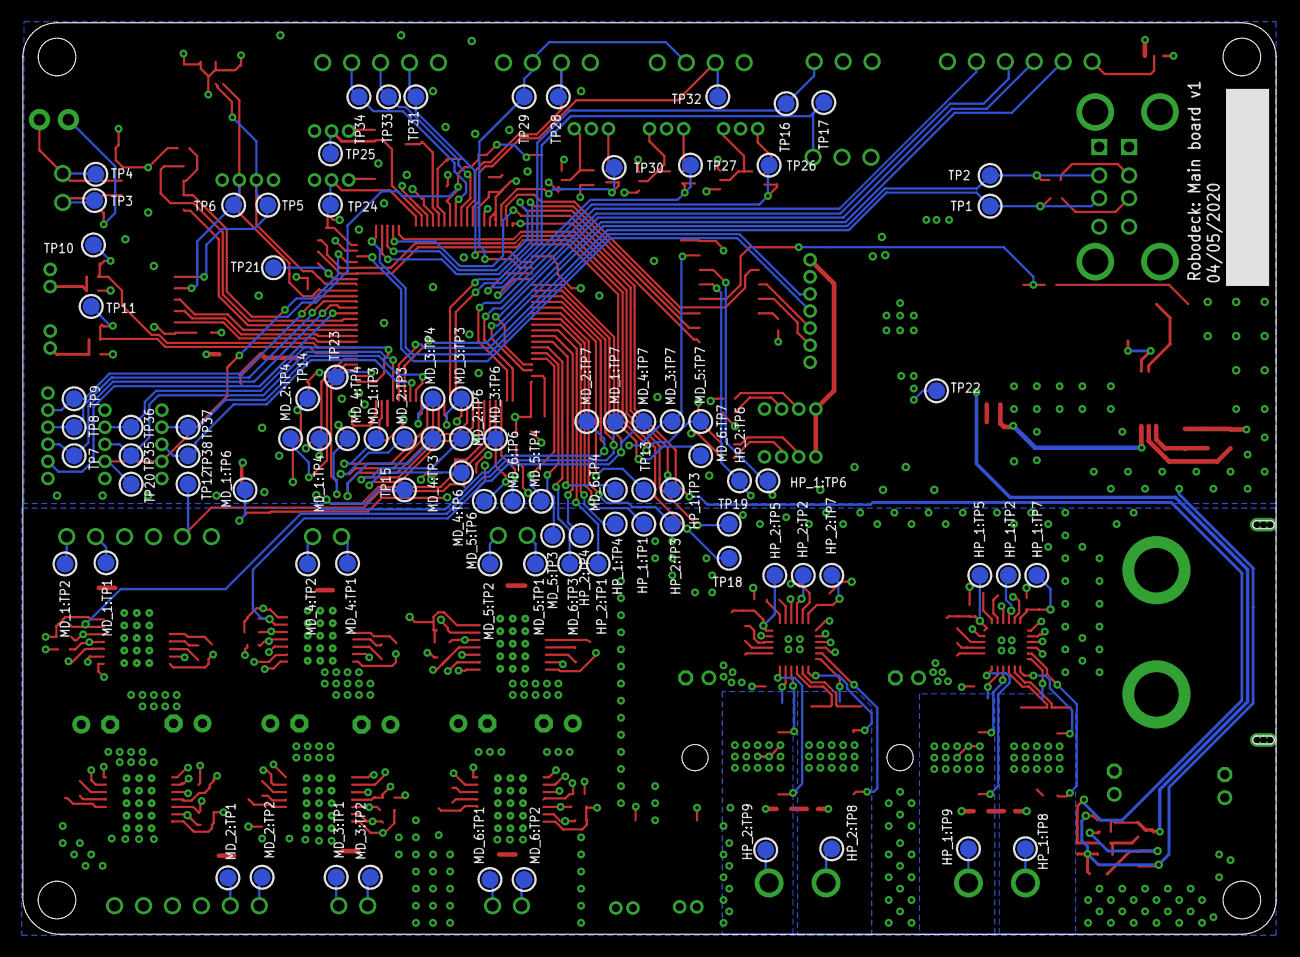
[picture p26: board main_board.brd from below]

Board: 4 copper layers, 110.0 x 80.0 mm, 336 parts (92 on the bottom side), 200 nets.

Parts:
C1, C2, C3, C4, C5, C8, C9, C10, C11, C12, C13, C16, C20, C23, C25, C28, C31, C33, C35, C37, C39, C40: 100nF; C0402
C6: 10uF; C0402
C7, C14, C15, C17, C34, C36, C38: 1uF; C0402
C18, C19: 2.2uF; C0402
C21, C22: 22pF; C0402
C24, C30: 10uF; C0805
C26: 47uF; C1206
C27: 0.47uF; C1206
C29: 1nF; C0603
C32: 1uF; C1206
C41: 330uF/50V; E2-5
C42: 4.7uF/50V; E2-5
C43: 10nF; C0402
C44, C45: 50pF; C0402
D1, D2: SBR3U40P1-7; SOD-123
D3: PMEG3030EP; SOD-128
D4: SK104
D5: MBR120; SOD-123
F1: TLC-MSMD250/16; 1812
HP_1:C1, HP_1:C2, HP_1:C3, HP_1:C5, HP_2:C1, HP_2:C2, HP_2:C3, HP_2:C5: 1uF; C0402
HP_1:C4, HP_1:C6, HP_2:C4, HP_2:C6: 100nF; C0402
HP_1:C7, HP_2:C7: 10nF; C0402
HP_1:C8, HP_2:C8: 4.7uF/50V; E2-5
HP_1:Q7, HP_1:Q8, HP_2:Q7, HP_2:Q8: AON6978; DFN-S-6X5-PP
HP_1:R1, HP_2:R1: 47k; R0402
HP_1:R2, HP_2:R2: 300k; R0402
HP_1:R3, HP_2:R3: DNP; R0402
HP_1:R5, HP_2:R5: 68k; R0402
HP_1:R6, HP_2:R6: 0R005; R2010
HP_1:R7, HP_2:R7: 1R; R0402
HP_1:TP1, HP_1:TP2, HP_1:TP3, HP_1:TP4, HP_1:TP5, HP_1:TP6, HP_1:TP7, HP_1:TP8, HP_1:TP9, HP_2:TP1, HP_2:TP2, HP_2:TP3, HP_2:TP4, HP_2:TP5, HP_2:TP6, HP_2:TP7, HP_2:TP8, HP_2:TP9: TESTPOINT_ROUND_1.5MM
HP_1:U1, HP_2:U1: DRV8701P; QFN24-4X4
HP_1:X1, HP_2:X1: B02P-NV
J1: XT-90-M; XT-90-M-SIDE
J2: USB_A_2; TE_1903815-1
L1: SPM6530T-4R7M
L3: WUERTH-ELEKTRONIK_1210
MD_1:C1, MD_1:C6, MD_2:C1, MD_2:C6, MD_3:C1, MD_3:C6, MD_4:C1, MD_4:C6, MD_5:C1, MD_5:C6, MD_6:C1, MD_6:C6: 22nF; C0402
MD_1:C2, MD_2:C2, MD_3:C2, MD_4:C2, MD_5:C2, MD_6:C2: 1uF; C0402
MD_1:C3, MD_1:C4, MD_2:C3, MD_2:C4, MD_3:C3, MD_3:C4, MD_4:C3, MD_4:C4, MD_5:C3, MD_5:C4, MD_6:C3, MD_6:C4: 100nF; C0402
MD_1:C5, MD_2:C5, MD_3:C5, MD_4:C5, MD_5:C5, MD_6:C5: 100uF; E2,5-7
MD_1:R1, MD_2:R1, MD_3:R1, MD_4:R1, MD_5:R1, MD_6:R1: 10k; R0402
MD_1:R2, MD_2:R2, MD_3:R2, MD_4:R2, MD_5:R2, MD_6:R2: 1.65k; R0402
MD_1:R3, MD_2:R3, MD_3:R3, MD_4:R3, MD_5:R3, MD_6:R3: 50; R0402
MD_1:TP1, MD_1:TP2, MD_1:TP3, MD_1:TP4, MD_1:TP6, MD_1:TP7, MD_2:TP1, MD_2:TP2, MD_2:TP3, MD_2:TP4, MD_2:TP6, MD_2:TP7, MD_3:TP1, MD_3:TP2, MD_3:TP3, MD_3:TP4, MD_3:TP6, MD_3:TP7, MD_4:TP1, MD_4:TP2, MD_4:TP3, MD_4:TP4, MD_4:TP6, MD_4:TP7, MD_5:TP1, MD_5:TP2, MD_5:TP3, MD_5:TP4, MD_5:TP6, MD_5:TP7, MD_6:TP1, MD_6:TP2, MD_6:TP3, MD_6:TP4, MD_6:TP6, MD_6:TP7: TESTPOINT_ROUND_1.5MM
MD_1:U1, MD_2:U1, MD_3:U1, MD_4:U1, MD_5:U1, MD_6:U1: DRV8876; IC_TPS92641PWP/NOPB
Q1, Q2: IRLHM630TRPBF; MLP8-33
Q3: SI7465DP; SI7465
Q4: DMG2302; SOT-23
R1, R2, R3, R4, R5, R6, R7, R8, R12, R17, R20, R21, R22, R29, R31, R34, R35, R39: 10k; R0402
R9: 120; R0402
R10, R11: 4.7k; R0402
R13: 40.2k; R0603
R14: 200; R0603
R15: 0.001ohm; R1206
R16: 200; R0402
R18: 3.09k; R0402
R19, R24, R26, R28, R33, R40, R41, R42, R43: DNP; R0402
R23, R25, R32: 0R; R0402
R27, R37, R38: 0; R0402
R30: 68k; R0402
R36: 20k; R0402
S1: RESET; TACTILE_SWITCH_SMD_5.2MM
SJ1, SJ2, SJ3, SJ4: SPARKFUN-PASSIVES_JUMPER_PAD-3-1&2_NC_BY_PASTE; SPARKFUN-PASSIVES_PAD-HUMPER-3-1&2_NC_BY_PASTE_YES_SILK_FUL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
SJ5: SOLDERJUMPER_REFLOW_NOPASTE
SP1: GSC9040YA-16R2700
TP1, TP2, TP3, TP4, TP5, TP6, TP7, TP8, TP9, TP10, TP11, TP12, TP13, TP14, TP15, TP16, TP17, TP18, TP19, TP20, TP21, TP22, TP23, TP24, TP25, TP26, TP27, TP28, TP29, TP30, TP31, TP32, TP33, TP34, TP35, TP36, TP37, TP38: TESTPOINT_ROUND_1.5MM
U1: BME280; PSON65P250X250X100-8N
U2: SN65HVD75DR; SOIC127P600X175-8N
U3: STM32F407VGT6; QFP50P1600X1600X160-100N
U4: AP2114H-3.3V- 1A; GEN_COMP_SOT223
U5: LM5085
U6: 74HC4051D; SOIC127P600X175-16N
U7: ACS723LLCTR-40AU (0-40A); SPARKFUN-SENSORS_SO08
X1, X2, X3, X4: B2B-ZR
X5, X6, X7, X8, X15: JST-XH-02
X9, X10, X22: JST-XH-06
X11, X12: JST-XH-03
X13, X17, X31: B4B-ZR
X14, X19, X28, X29, X30: B3B-ZR
X16: 1X02
X18: B6B-ZR
X20, X21: B5B-ZR
X23, X24: JST-XH-04
X25: JST-XH-05
X26: B7B-ZR
X27: BM08B-SRSS-TB
XTAL1: 25MHz; NX3225

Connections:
+3V3: C3.1, C4.1, C5.1, C8.1, C9.1, C10.1, C11.1, C12.1, C13.1, C14.1, C15.1, C16.1, C17.1, C25.1, C30.1, C31.2, C39.2, D5.C, HP_1:R2.2, HP_1:R5.2, HP_2:R2.2, HP_2:R5.2, MD_1:R1.2, MD_1:U1.16, MD_2:R1.2, MD_2:U1.16, MD_3:R1.2, MD_3:U1.16, MD_4:R1.2, MD_4:U1.16, MD_5:R1.2, MD_5:U1.16, MD_6:R1.2, MD_6:U1.16, R1.2, R3.2, R5.1, R6.1, R10.2, R11.2, R19.1, R20.2, R21.2, R22.2, R27.1, R39.2, SJ1.3, SJ2.3, SJ3.3, SJ4.3, SP1.P$3, TP22.P$1, U1.2, U1.6, U1.8, U2.8, U3.11, U3.19, U3.21, U3.22, U3.28, U3.50, U3.75, U3.100, U4.2, U4.4, U6.16, X9.4, X10.4, X17.1, X18.1, X19.1, X20.1, X21.1, X23.1, X24.1, X25.1, X26.6, X27.1, X28.1
+5V: C23.1, C24.1, C40.1, D3.A, L1.2, R16.2, R17.2, R34.2, SJ1.1, SJ2.1, SJ3.1, SJ4.1, U4.3, U7.8, X11.1, X12.1, X13.1, X26.7, X31.1
+24V: C26.1, C27.1, C29.2, C32.1, D1.C, D2.C, HP_1:C5.2, HP_1:C6.1, HP_1:C8.+, HP_1:Q7.P$2, HP_1:Q7.P$3, HP_1:Q7.P$4, HP_1:Q7.P$234A, HP_1:Q7.P$234B, HP_1:Q8.P$2, HP_1:Q8.P$3, HP_1:Q8.P$4, HP_1:Q8.P$234A, HP_1:Q8.P$234B, HP_1:U1.1, HP_2:C5.2, HP_2:C6.1, HP_2:C8.+, HP_2:Q7.P$2, HP_2:Q7.P$3, HP_2:Q7.P$4, HP_2:Q7.P$234A, HP_2:Q7.P$234B, HP_2:Q8.P$2, HP_2:Q8.P$3, HP_2:Q8.P$4, HP_2:Q8.P$234A, HP_2:Q8.P$234B, HP_2:U1.1, MD_1:C3.1, MD_1:C4.1, MD_1:C5.+, MD_1:U1.11, MD_2:C3.1, MD_2:C4.1, MD_2:C5.+, MD_2:U1.11, MD_3:C3.1, MD_3:C4.1, MD_3:C5.+, MD_3:U1.11, MD_4:C3.1, MD_4:C4.1, MD_4:C5.+, MD_4:U1.11, MD_5:C3.1, MD_5:C4.1, MD_5:C5.+, MD_5:U1.11, MD_6:C3.1, MD_6:C4.1, MD_6:C5.+, MD_6:U1.11, R13.1, R14.2, R15.2, R30.2, U5.8, U7.3, U7.4, X3.1, X4.1
A: R9.2, TP3.P$1, U2.6, X15.2
AGND: C41.-, C42.-, HP_1:C1.2, HP_1:C2.2, HP_1:C3.2, HP_1:C6.2, HP_1:C8.-, HP_1:R1.1, HP_1:R3.1, HP_1:R6.1, HP_1:U1.5, HP_1:U1.16, HP_1:U1.20, HP_1:U1.EXP, HP_2:C1.2, HP_2:C2.2, HP_2:C3.2, HP_2:C6.2, HP_2:C8.-, HP_2:R1.1, HP_2:R3.1, HP_2:R6.1, HP_2:U1.5, HP_2:U1.16, HP_2:U1.20, HP_2:U1.EXP, J1.2, J1.P$1, J1.P$2, J1.P$3, J1.P$4, J1.P$5, J1.P$6, L3.2, MD_1:C4.2, MD_1:C5.-, MD_1:U1.9, MD_1:U1.17, MD_1:U1.18, MD_1:U1.19, MD_1:U1.20, MD_1:U1.21, MD_1:U1.22, MD_1:U1.23, MD_1:U1.24, MD_1:U1.25, MD_1:U1.26, MD_1:U1.27, MD_1:U1.28, MD_1:U1.29, MD_1:U1.30, MD_1:U1.31, MD_1:U1.32, MD_2:C4.2, MD_2:C5.-, MD_2:U1.9, MD_2:U1.17, MD_2:U1.18, MD_2:U1.19, MD_2:U1.20, MD_2:U1.21, MD_2:U1.22, MD_2:U1.23, MD_2:U1.24, MD_2:U1.25, MD_2:U1.26, MD_2:U1.27, MD_2:U1.28, MD_2:U1.29, MD_2:U1.30, MD_2:U1.31, MD_2:U1.32, MD_3:C4.2, MD_3:C5.-, MD_3:U1.9, MD_3:U1.17, MD_3:U1.18, MD_3:U1.19, MD_3:U1.20, MD_3:U1.21, MD_3:U1.22, MD_3:U1.23, MD_3:U1.24, MD_3:U1.25, MD_3:U1.26, MD_3:U1.27, MD_3:U1.28, MD_3:U1.29, MD_3:U1.30, MD_3:U1.31, MD_3:U1.32, MD_4:C4.2, MD_4:C5.-, MD_4:U1.9, MD_4:U1.17, MD_4:U1.18, MD_4:U1.19, MD_4:U1.20, MD_4:U1.21, MD_4:U1.22, MD_4:U1.23, MD_4:U1.24, MD_4:U1.25, MD_4:U1.26, MD_4:U1.27, MD_4:U1.28, MD_4:U1.29, MD_4:U1.30, MD_4:U1.31, MD_4:U1.32, MD_5:C4.2, MD_5:C5.-, MD_5:U1.9, MD_5:U1.17, MD_5:U1.18, MD_5:U1.19, MD_5:U1.20, MD_5:U1.21, MD_5:U1.22, MD_5:U1.23, MD_5:U1.24, MD_5:U1.25, MD_5:U1.26, MD_5:U1.27, MD_5:U1.28, MD_5:U1.29, MD_5:U1.30, MD_5:U1.31, MD_5:U1.32, MD_6:C4.2, MD_6:C5.-, MD_6:U1.9, MD_6:U1.17, MD_6:U1.18, MD_6:U1.19, MD_6:U1.20, MD_6:U1.21, MD_6:U1.22, MD_6:U1.23, MD_6:U1.24, MD_6:U1.25, MD_6:U1.26, MD_6:U1.27, MD_6:U1.28, MD_6:U1.29, MD_6:U1.30, MD_6:U1.31, MD_6:U1.32, Q1.S1, Q1.S2, Q1.S3, Q2.S1, Q2.S2, Q2.S3
AMUX_OUT: U3.24, U6.3
AMUX_S0: U3.2, U6.11
AMUX_S1: U3.3, U6.10
AMUX_S2: U3.4, U6.9
B: TP4.P$1, U2.7, X15.1, X16.2
BAT_IN: C41.+, C42.+, J1.1, U7.1, U7.2
BAT_MEAS: R30.1, R31.2, U6.12
BUMPER1: C1.1, R4.2, TP10.P$1, U3.82
BUMPER2: C2.1, R2.2, TP11.P$1, U3.81
BUZZER: Q4.G, R29.1, TP23.P$1, U3.77
CENTRAL_BRUSH_A: MD_4:TP3.P$1, MD_4:U1.1, U3.64
CENTRAL_BRUSH_B: MD_4:TP4.P$1, MD_4:U1.2, U3.78
CENTRAL_BRUSH_CURRENT: MD_4:R2.1, MD_4:TP7.P$1, MD_4:U1.6, U3.34
CENTRAL_BRUSH_FAULT: MD_4:R1.1, MD_4:TP6.P$1, MD_4:U1.4, U3.58
CLEAN/STAIN: U3.83, X27.2
CLIFF1_OUT: TP28.P$1, U3.17, X24.2
CLIFF2_OUT: TP32.P$1, U3.18, X23.2
CLIFF_CTL: TP29.P$1, U3.30, X23.3, X24.3
CS: U3.88, X18.5
DRIVE1_A: MD_1:TP3.P$1, MD_1:U1.1, U3.66
DRIVE1_B: MD_1:TP4.P$1, MD_1:U1.2, U3.80
DRIVE1_CURRENT: MD_1:R2.1, MD_1:TP7.P$1, MD_1:U1.6, U3.35
DRIVE1_FAULT: MD_1:R1.1, MD_1:TP6.P$1, MD_1:U1.4, U3.60
DRIVE1_OUT_A: MD_1:C6.1, MD_1:TP2.P$1, MD_1:U1.8, X9.1
DRIVE1_OUT_B: MD_1:R3.2, MD_1:TP1.P$1, MD_1:U1.10, X9.2
DRIVE2_A: MD_2:TP3.P$1, MD_2:U1.1, U3.65
DRIVE2_B: MD_2:TP4.P$1, MD_2:U1.2, U3.79
DRIVE2_CURRENT: MD_2:R2.1, MD_2:TP7.P$1, MD_2:U1.6, U3.36
DRIVE2_FAULT: MD_2:R1.1, MD_2:TP6.P$1, MD_2:U1.4, U3.59
DRIVE2_OUT_A: MD_2:C6.1, MD_2:TP2.P$1, MD_2:U1.8, X10.1
DRIVE2_OUT_B: MD_2:R3.2, MD_2:TP1.P$1, MD_2:U1.10, X10.2
D_N: J2.6, R37.1, TP2.P$1, U3.70
D_P: J2.7, R38.1, TP1.P$1, U3.71
ENCODER1: C44.1, R5.2, TP12.P$1, U3.55, X9.5
ENCODER2: C45.1, R6.2, TP15.P$1, U3.56, X10.5
EXT_TEMP1: R21.1, TP24.P$1, U3.8, X19.2
EXT_TEMP2: R22.1, TP25.P$1, U3.9, X28.2
GAP_CTL: TP31.P$1, U3.29, X25.2
GAP_SENSE_1: TP34.P$1, U3.15, X25.4
GAP_SENSE_2: TP33.P$1, U3.16, X25.3
GND: C1.2, C2.2, C3.2, C4.2, C5.2, C6.1, C7.1, C8.2, C9.2, C10.2, C11.2, C12.2, C13.2, C14.2, C15.2, C16.2, C17.2, C18.2, C19.2, C20.2, C21.1, C22.1, C23.2, C24.2, C25.2, C26.2, C28.1, C30.2, C31.1, C32.2, C33.2, C34.2, C35.2, C36.2, C37.2, C38.2, C39.1, C40.2, C43.2, C44.2, C45.2, D4.1, J2.4, J2.8, J2.P1, J2.P2, J2.P3, J2.P4, L3.1, MD_1:C2.2, MD_1:R2.2, MD_1:U1.7, MD_1:U1.15, MD_2:C2.2, MD_2:R2.2, MD_2:U1.7, MD_2:U1.15, MD_3:C2.2, MD_3:R2.2, MD_3:U1.7, MD_3:U1.15, MD_4:C2.2, MD_4:R2.2, MD_4:U1.7, MD_4:U1.15, MD_5:C2.2, MD_5:R2.2, MD_5:U1.7, MD_5:U1.15, MD_6:C2.2, MD_6:R2.2, MD_6:U1.7, MD_6:U1.15, Q4.S, R7.2, R8.2, R12.1, R18.1, R24.1, R26.1, R28.2, R29.2, R31.1, R33.1, R36.1, S1.3, S1.4, SJ5.2, U1.1, U1.5, U1.7, U2.5, U3.10, U3.20, U3.27, U3.74, U3.99, U4.1, U5.4, U5.9, U6.7, U6.8, U7.5, X1.2, X2.2, X9.3, X10.3, X11.2, X12.2, X13.4, X14.2, X17.4, X18.6, X19.3, X20.5, X21.5, X22.6, X23.4, X24.4, X25.5, X26.1, X27.7, X27.8, X28.3, X29.2, X30.2, X31.4, XTAL1.2, XTAL1.4
HP_1:!OC: HP_1:TP2.P$1, HP_1:U1.10
HP_1:ACT4_DRIVE+: HP_1:Q8.P$9, HP_1:R7.2, HP_1:TP8.P$1, HP_1:U1.18, HP_1:X1.1
HP_1:ACT4_DRIVE-: HP_1:C7.1, HP_1:Q7.P$9, HP_1:TP9.P$1, HP_1:U1.23, HP_1:X1.2
HP_1:AVDD: HP_1:C2.1, HP_1:U1.7
HP_1:N$4: HP_1:Q8.P$8, HP_1:U1.19
HP_1:N$40: HP_1:C4.1, HP_1:U1.3
HP_1:N$41: HP_1:C4.2, HP_1:U1.4
HP_1:N$44: HP_1:Q7.P$5, HP_1:Q7.P$6, HP_1:Q7.P$7, HP_1:Q8.P$5, HP_1:Q8.P$6, HP_1:Q8.P$7, HP_1:R6.2, HP_1:U1.21
HP_1:N$45: HP_1:R3.2, HP_1:R5.1, HP_1:TP7.P$1, HP_1:U1.12
HP_1:N$46: HP_1:Q7.P$8, HP_1:U1.22
HP_1:N$49: HP_1:C5.1, HP_1:U1.2
HP_1:N$50: HP_1:C3.1, HP_1:U1.8
HP_1:N$52: HP_1:Q8.P$1, HP_1:U1.17
HP_1:N$53: HP_1:Q7.P$1, HP_1:U1.24
HP_1:N$77: HP_1:C7.2, HP_1:R7.1
HP_1:VREF: HP_1:C1.1, HP_1:R1.2, HP_1:R2.1, HP_1:TP5.P$1, HP_1:U1.6
HP_2:!OC: HP_2:TP2.P$1, HP_2:U1.10
HP_2:ACT4_DRIVE+: HP_2:Q8.P$9, HP_2:R7.2, HP_2:TP8.P$1, HP_2:U1.18, HP_2:X1.1
HP_2:ACT4_DRIVE-: HP_2:C7.1, HP_2:Q7.P$9, HP_2:TP9.P$1, HP_2:U1.23, HP_2:X1.2
HP_2:AVDD: HP_2:C2.1, HP_2:U1.7
HP_2:N$4: HP_2:Q8.P$8, HP_2:U1.19
HP_2:N$40: HP_2:C4.1, HP_2:U1.3
HP_2:N$41: HP_2:C4.2, HP_2:U1.4
HP_2:N$44: HP_2:Q7.P$5, HP_2:Q7.P$6, HP_2:Q7.P$7, HP_2:Q8.P$5, HP_2:Q8.P$6, HP_2:Q8.P$7, HP_2:R6.2, HP_2:U1.21
HP_2:N$45: HP_2:R3.2, HP_2:R5.1, HP_2:TP7.P$1, HP_2:U1.12
HP_2:N$46: HP_2:Q7.P$8, HP_2:U1.22
HP_2:N$49: HP_2:C5.1, HP_2:U1.2
HP_2:N$50: HP_2:C3.1, HP_2:U1.8
HP_2:N$52: HP_2:Q8.P$1, HP_2:U1.17
HP_2:N$53: HP_2:Q7.P$1, HP_2:U1.24
HP_2:N$77: HP_2:C7.2, HP_2:R7.1
HP_2:VREF: HP_2:C1.1, HP_2:R1.2, HP_2:R2.1, HP_2:TP5.P$1, HP_2:U1.6
L-CURRENT: R35.1, R36.2, U3.25
MD_1:N$1: MD_1:C1.2, MD_1:U1.14
MD_1:N$2: MD_1:C1.1, MD_1:U1.13
MD_1:N$3: MD_1:C3.2, MD_1:U1.12
MD_1:N$4: MD_1:C6.2, MD_1:R3.1
MD_2:N$1: MD_2:C1.2, MD_2:U1.14
MD_2:N$2: MD_2:C1.1, MD_2:U1.13
MD_2:N$3: MD_2:C3.2, MD_2:U1.12
MD_2:N$4: MD_2:C6.2, MD_2:R3.1
MD_3:N$1: MD_3:C1.2, MD_3:U1.14
MD_3:N$2: MD_3:C1.1, MD_3:U1.13
MD_3:N$3: MD_3:C3.2, MD_3:U1.12
MD_3:N$4: MD_3:C6.2, MD_3:R3.1
MD_4:N$1: MD_4:C1.2, MD_4:U1.14
MD_4:N$2: MD_4:C1.1, MD_4:U1.13
MD_4:N$3: MD_4:C3.2, MD_4:U1.12
MD_4:N$4: MD_4:C6.2, MD_4:R3.1
MD_5:N$1: MD_5:C1.2, MD_5:U1.14
MD_5:N$2: MD_5:C1.1, MD_5:U1.13
MD_5:N$3: MD_5:C3.2, MD_5:U1.12
MD_5:N$4: MD_5:C6.2, MD_5:R3.1
MD_6:N$1: MD_6:C1.2, MD_6:U1.14
MD_6:N$2: MD_6:C1.1, MD_6:U1.13
MD_6:N$3: MD_6:C3.2, MD_6:U1.12
MD_6:N$4: MD_6:C6.2, MD_6:R3.1
MISO: TP8.P$1, U3.90, X18.3
MOSI: TP9.P$1, U3.91, X18.2
MOTOR_SLEEP: HP_1:U1.13, HP_2:U1.13, MD_1:U1.3, MD_2:U1.3, MD_3:U1.3, MD_4:U1.3, MD_5:U1.3, MD_6:U1.3, R20.1, TP13.P$1, U3.37
M_VREF: MD_1:C2.1, MD_1:U1.5, MD_2:C2.1, MD_2:U1.5, MD_3:C2.1, MD_3:U1.5, MD_4:C2.1, MD_4:U1.5, MD_5:C2.1, MD_5:U1.5, MD_6:C2.1, MD_6:U1.5, R27.2, R28.1, TP14.P$1
unnamed: R2.1, R3.1, X2.1
unnamed: MD_3:C6.1, MD_3:TP2.P$1, MD_3:U1.8, X5.1
unnamed: R1.1, R4.1, X1.1
unnamed: MD_3:R3.2, MD_3:TP1.P$1, MD_3:U1.10, X5.2
unnamed: MD_5:C6.1, MD_5:TP2.P$1, MD_5:U1.8, X7.1
unnamed: MD_5:R3.2, MD_5:TP1.P$1, MD_5:U1.10, X7.2
unnamed: MD_6:C6.1, MD_6:TP2.P$1, MD_6:U1.8, X8.1
unnamed: MD_6:R3.2, MD_6:TP1.P$1, MD_6:U1.10, X8.2
unnamed: MD_4:C6.1, MD_4:TP2.P$1, MD_4:U1.8, X6.1
unnamed: MD_4:R3.2, MD_4:TP1.P$1, MD_4:U1.10, X6.2
unnamed: D2.A, Q2.D1, Q2.D2, Q2.D3, Q2.D4, Q2.DRAIN0, X4.2
unnamed: D1.A, Q1.D1, Q1.D2, Q1.D3, Q1.D4, Q1.DRAIN0, X3.2
unnamed: R9.1, X16.1
unnamed: C18.1, U3.73
unnamed: C19.1, U3.49
unnamed: R12.2, TP21.P$1, U3.94
unnamed: SJ1.2, X22.1
unnamed: D3.K, F1.1
unnamed: D5.A, Q4.D, SP1.P$2
unnamed: R23.2, X14.1
unnamed: C33.1, C34.1, SJ2.2, X14.3
unnamed: R25.2, X29.1
unnamed: C28.2, R16.1
unnamed: C35.1, C36.1, SJ3.2, X29.3
unnamed: R32.2, X30.1
unnamed: C37.1, C38.1, SJ4.2, X30.3
unnamed: R13.2, U5.2
unnamed: C43.1, R35.2, U7.7
unnamed: J2.2, R37.2
unnamed: J2.3, R38.2
unnamed: R34.1, SJ5.1, U7.6
unnamed: R42.2, X13.2
unnamed: R39.1, U6.6
unnamed: R43.2, X13.3
unnamed: R40.2, X31.2
unnamed: R41.2, X31.3
unnamed: Q3.1, Q3.2, Q3.3, R15.1, U5.5
unnamed: C29.1, R14.1, U5.1
unnamed: R17.1, R18.2, U5.3
unnamed: C27.2, U5.7
unnamed: D4.2, L1.1, Q3.5, Q3.6, Q3.7, Q3.8, Q3.9
unnamed: Q3.4, U5.6
ON/OFF: U3.85, X27.4
PRESSURE1: R32.1, R33.2, TP30.P$1, U3.23
PRESSURE2: R23.1, R24.2, TP27.P$1, U3.31
PRESSURE3: R25.1, R26.2, TP26.P$1, U3.32
PRESSURE_PUMP_A: MD_3:TP3.P$1, MD_3:U1.1, U3.63
PRESSURE_PUMP_B: MD_3:TP4.P$1, MD_3:U1.2, U3.67
PRESSURE_PUMP_CURRENT: MD_3:R2.1, MD_3:TP7.P$1, MD_3:U1.6, U6.15
PRESSURE_PUMP_FAULT: MD_3:R1.1, MD_3:TP6.P$1, MD_3:U1.4, U3.57
RESET: C20.1, S1.1, S1.2, TP20.P$1, U3.14, X20.4, X21.4
RS485_DIR: R19.2, U2.2, U2.3, U3.97
RS485_RX: U2.1, U3.87
RS485_TX: U2.4, U3.86
SCK: TP7.P$1, U3.89, X18.4
SCL: R11.1, TP6.P$1, U1.4, U3.92, X17.2, X27.5
SCRUBBER1_A: MD_5:TP3.P$1, MD_5:U1.1, U3.45
SCRUBBER1_B: MD_5:TP4.P$1, MD_5:U1.2, U3.46
SCRUBBER1_CURRENT: MD_5:R2.1, MD_5:TP7.P$1, MD_5:U1.6, U3.26
SCRUBBER1_FAULT: MD_5:R1.1, MD_5:TP6.P$1, MD_5:U1.4, U3.54
SCRUBBER2_A: MD_6:TP3.P$1, MD_6:U1.1, U3.44
SCRUBBER2_B: MD_6:TP4.P$1, MD_6:U1.2, U3.43
SCRUBBER2_CURRENT: MD_6:R2.1, MD_6:TP7.P$1, MD_6:U1.6, U3.33
SCRUBBER2_FAULT: MD_6:R1.1, MD_6:TP6.P$1, MD_6:U1.4, U3.53
SDA: R10.1, TP5.P$1, U1.3, U3.93, X17.3, X27.6
SERVO1: TP16.P$1, U3.62, X11.3
SERVO2: TP17.P$1, U3.61, X12.3
SMBUS_ALERT: U3.51, X22.4
SMBUS_IO: U3.52, X22.5
SMBUS_SCL: U3.47, X22.3
SMBUS_SDA: U3.48, X22.2
SOLENOID1: Q1.GATE, R7.1, TP18.P$1, U3.95
SOLENOID2: Q2.GATE, R8.1, TP19.P$1, U3.96
SPARE_ANALOG1: U6.5, X26.2
SPARE_ANALOG2: U6.4, X26.3
SPARE_GPIO1: U3.98, X26.4
SPARE_GPIO2: U3.1, X26.5
STAINING_FAN1_A: HP_1:TP4.P$1, HP_1:U1.15, R40.1, U3.40
STAINING_FAN1_B: HP_1:TP1.P$1, HP_1:U1.14, U3.39
STAINING_FAN1_CURRENT: HP_1:TP6.P$1, HP_1:U1.11, U6.14
STAINING_FAN1_FAULT: HP_1:TP3.P$1, HP_1:U1.9, R41.1, U3.5
STAINING_FAN2_A: HP_2:TP4.P$1, HP_2:U1.15, R42.1, U3.42
STAINING_FAN2_B: HP_2:TP1.P$1, HP_2:U1.14, U3.41
STAINING_FAN2_CURRENT: HP_2:TP6.P$1, HP_2:U1.11, U6.13
STAINING_FAN2_FAULT: HP_2:TP3.P$1, HP_2:U1.9, R43.1, U3.38
START/STOP: U3.84, X27.3
SWCLK: TP36.P$1, U3.76, X20.2
SWDIO: TP35.P$1, U3.72, X20.3
USART1_RX: TP38.P$1, U3.69, X21.3
USART1_TX: TP37.P$1, U3.68, X21.2
VUSB: C6.2, C7.2, F1.2, J2.1, J2.5
X_N: C22.2, U3.13, XTAL1.3
X_P: C21.2, U3.12, XTAL1.1

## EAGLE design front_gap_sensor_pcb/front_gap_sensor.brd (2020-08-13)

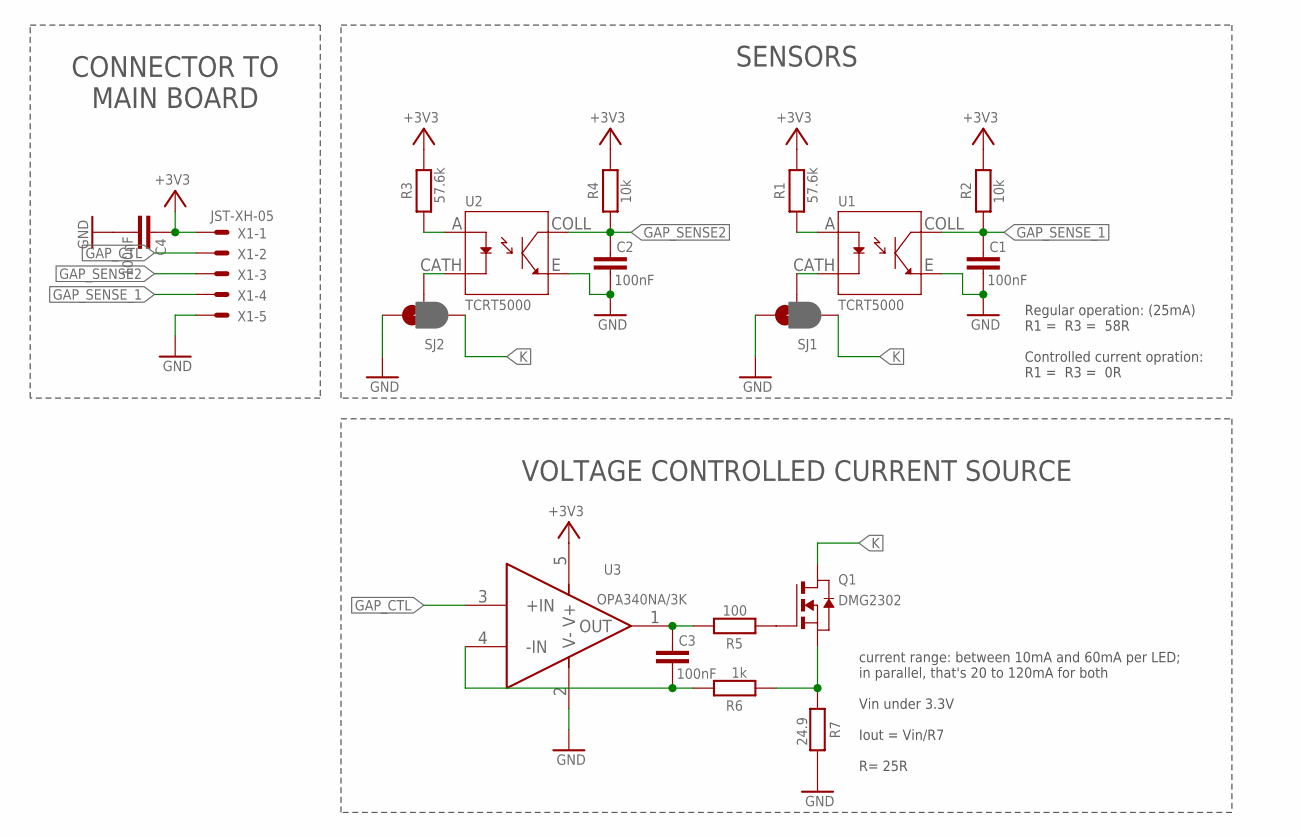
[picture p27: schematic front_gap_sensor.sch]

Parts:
C1, C2, C3, C4: 100nF; C0402
Q1: DMG2302; SOT-23
R1, R3: 57.6k; R0402
R2, R4: 10k; R0402
R5: 100; R0402
R6: 1k; R0402
R7: 24.9; R0402
SJ1, SJ2: SPARKFUN-PASSIVES_JUMPER_PAD-3-1&2_NC_BY_PASTE; SPARKFUN-PASSIVES_PAD-HUMPER-3-1&2_NC_BY_PASTE_YES_SILK_FUL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
U1, U2: TCRT5000; OPTO_TCRT5000
U3: OPA340NA/3K; SOT95P280X145-5N
X1: JST-XH-05; JST-XH-05-PACKAGE-ROUND-PAD

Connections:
+3V3: C4.2, R1.2, R2.2, R3.2, R4.2, U3.5 (V+), X1.1
GAP_CTL: U3.3 (+IN), X1.2
GAP_SENSE2: C2.2, R4.1, U2.COLL, X1.3
GAP_SENSE_1: C1.2, R2.1, U1.COLL, X1.4
GND: C1.1, C2.1, C4.1, R7.2, SJ1.3, SJ2.3, U1.E, U2.E, U3.2 (V-), X1.5
K: Q1.D, SJ1.1, SJ2.1
K_1: SJ2.2, U2.CATH
unnamed: SJ1.2, U1.CATH
unnamed: C3.2, R5.2, U3.1 (OUT)
unnamed: C3.1, R6.2, U3.4 (-IN)
unnamed: Q1.G, R5.1
unnamed: Q1.S, R6.1, R7.1
S_IN1: R3.1, U2.A
S_IN2: R1.1, U1.A

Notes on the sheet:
Regular operation: (25mA) R1 = R3 = 58R Controlled current opration: R1 = R3 = 0R
SENSORS
CONNECTOR TO MAIN BOARD
VOLTAGE CONTROLLED CURRENT SOURCE
current range: between 10mA and 60mA per LED; in parallel, that's 20 to 120mA for both Vin under 3.3V Iout = Vin/R7 R= 25R



Board: 2 copper layers, 30.0 x 15.0 mm, 18 parts (2 on the bottom side), 14 nets.

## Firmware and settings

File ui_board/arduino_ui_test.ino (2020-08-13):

/*
Code to test the Robodeck UI board using an arduino
*/
#include <Wire.h>
//make sure you download the Adafruit_MCP23008 library: you can clone it from github or 
//get it from the Arduino Library manager
#include "Adafruit_MCP23008.h"

#define button1 2
#define button2 3 
//The Arduino Uno board I used to test the boards only has 2 interrupt pins. 
//To test the third one, just swap the connections.  

volatile bool flag1, flag2;

//Create and instance of the MCP23008 instance
Adafruit_MCP23008 mcp;

void setup(){
    Serial.begin(9600);
    // init I/O expander
    mcp.begin();
    // init pins 
    pinMode(button1, INPUT);
    pinMode(button2, INPUT);
    mcp.pinMode(0, INPUT); // we need to set this one as input to make sure both RED and GREEN LED stay off
    mcp.pinMode(1, OUTPUT);
    mcp.pinMode(2, OUTPUT);
    mcp.pinMode(3, OUTPUT);
    mcp.pinMode(4, OUTPUT);
    mcp.pinMode(5, OUTPUT);
    mcp.pinMode(6, OUTPUT);
    mcp.pinMode(7, OUTPUT);

    mcp.digitalWrite(1, LOW); // turning the BLUE LED OFF
    mcp.digitalWrite(2, HIGH); // making sure the RGB LEDs stay off
    mcp.digitalWrite(3, HIGH);
    mcp.digitalWrite(4, HIGH);
    mcp.digitalWrite(5, HIGH);
    mcp.digitalWrite(6, HIGH);
    mcp.digitalWrite(7, HIGH);

    // interrupts for two of the buttons 
    attachInterrupt(digitalPinToInterrupt(button1), button1_isr, FALLING);
    attachInterrupt(digitalPinToInterrupt(button2), button2_isr, FALLING);
}

void loop(){

    toggle_all();
}

void button1_isr(){
    Serial.println("Button1 pressed!");
}

void button2_isr(){
    Serial.println("Button2 pressed!");
}

void toggle_all(){

    //Green/Red LED
    mcp.pinMode(0, OUTPUT);
    mcp.digitalWrite(0, HIGH);
    delay(500);
    mcp.digitalWrite(0, LOW);
    delay(500);
    mcp.pinMode(0, INPUT);

    //Blue LED
    mcp.digitalWrite(1, HIGH);
    delay(500);
    mcp.digitalWrite(1, LOW);
    delay(500);
    
    //RGB LED1
    mcp.digitalWrite(2, LOW);
    delay(500);
    mcp.digitalWrite(2, HIGH);
    delay(500);
    mcp.digitalWrite(3, LOW);
    delay(500);
    mcp.digitalWrite(3, HIGH);
    delay(500);
    mcp.digitalWrite(4, LOW);
    delay(500);
    mcp.digitalWrite(4, HIGH);
    delay(500);

    //RGB LED2
    mcp.digitalWrite(5, LOW);
    delay(500);
    mcp.digitalWrite(5, HIGH);
    delay(500);
    mcp.digitalWrite(6, LOW);
    delay(500);
    mcp.digitalWrite(6, HIGH);
    delay(500);
    mcp.digitalWrite(7, LOW);
    delay(500);
    mcp.digitalWrite(7, HIGH);
    delay(500); 
}

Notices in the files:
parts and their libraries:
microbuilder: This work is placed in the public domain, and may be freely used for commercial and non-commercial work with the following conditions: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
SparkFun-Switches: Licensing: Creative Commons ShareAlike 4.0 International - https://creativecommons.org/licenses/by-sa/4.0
